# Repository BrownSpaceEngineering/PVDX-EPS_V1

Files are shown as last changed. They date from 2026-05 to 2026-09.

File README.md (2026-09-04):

# EPS_V1

Electrical Power System (EPS) for PVDX — battery charging, regulation, and power distribution.

## Status
- Design phase: layout
- Current rev: rev-1.3
- Contributors: Kelly Lin, Natalie Cavallo, Jayla Hsiung, Nick Cavallo, Emily Zhang, Dean Zweiman

## System overview

Four 2S battery packs (8x Tenergy 30005-0 18650 cells) feed a charge/regulation chain built entirely from dedicated power-management ICs, with no onboard MCU — charging, cell balancing, and telemetry are handled in hardware and reported to the compute board over I2C.

**Board sheets:**

- **Battery Pack 1–4**: one **MP2672AGD-0000-Z** charger per pack handles charging, discharging, and cell balancing without needing a microcontroller to manage the process. One **MAX17205** fuel gauge per pack reports state-of-charge and battery telemetry to the compute board over its own I2C pair (SDA/SCL), so each of the 4 packs has an independent data channel — a single fuel-gauge/charger failure doesn't take down monitoring for the other packs.
- **Charging Inputs**: the **MP28167GQ-Z** converts solar input down to a fixed 5V for charging. A **TPS2121RUXR** power mux sits between the solar and external-5V inputs and picks whichever is present, prioritizing external input — this is what lets the board charge normally on the bench (external 5V) without needing solar illumination, while still working correctly on orbit.
- **Converters**: three fixed-output regulators step the ~6–8.4V battery bus down to the rails other subsystems actually need: **TPS62133RGTR** (5V), **TPS62132RGTR** (3.3V), and **TPS61088RHLR** (12V boost, needed since 12V is above the battery bus voltage).
- **Connectors**: battery pack I/O, the RBF (remove-before-flight) pin, inhibit switches (mechanically disconnect batteries from load/ground when pressed — a safety requirement, not just a connector), and the ALRT signal and I2C breakout to the compute board.

### Repo layout

```
EPS_V1/
├── EPS_V1.kicad_pro / .kicad_sch / .kicad_pcb / .step
├── fp-lib-table, sym-lib-table
├── schematics/          # sub-sheets
├── libs/
│   ├── footprints.pretty/
│   ├── symbols/
│   └── 3dmodels/
├── spice/
│   ├── sims/
│   └── models/
├── tools/                # SPICE model translator script
└── manufacturing/
    └── rev-<N>_<date>/
        ├── gerbers/
        ├── bom/
        └── plots/
```

**Why 2S battery packs specifically:** 4x 2S (8 cells total) rather than one large pack — this is a mechanical/electrical packing choice under the ISS 80 Wh limit, and it gives pack-level redundancy (a single pack failure doesn't take down the whole EPS). It also matters electrically: a 2S pack has a ~6.0V floor, which the buck converters can cleanly step down to 5V and 3.3V — a single-cell pack's ~3.0V floor wouldn't support that.

## Key design notes

- **Charge voltage 4.2V, typical 3.6V, overdischarge floor raised from the cell's rated 2.75V to 3.0V** — added margin above the cell's absolute minimum.
- **MP2672A output current is being restricted below the MP28167GQ-Z's 3A capability** to stay under the board's actual current requirement (2.52A = 14/5×0.9). Open question below on whether that restriction should assume all 4 packs charging at once.
- **MAX17205's external-thermistor input is intentionally unused** — flight software reads temperature from the analog thermistor connection straight to the compute board instead, not through the fuel gauge.
- **TPS61088 (12V) key values:** 200kHz min switching frequency (840k resistor), 3A current limit (400k), PFM mode (MODE pin floating), R1 502k / R2 56k for 12V output, 2.2µH inductor per TI's recommended table.
- **Thermistor (NXFT15XV103FEAB025):** system draws 0.574mW through it against a 3mW rating — comfortable margin. Rated -40°C to 125°C.

## Simulations
- `spice/sims/` — EPS_U6, U2_EPS, U3_EPS, U6_EPS (regulator sims)
- `spice/models/` — TI PSpice models for TPS61088/TPS62132/TPS62133, both original and LTSpice-collapsed versions
- `tools/` — script + requirements to collapse TI's multi-line `.lib` continuation format into something LTSpice's autogenerator can parse

## Manufacturing history
| Rev | Date | Notes | Location |
|-----|---|---|---|
| 1.0 | 5/15/26 | First layout pass | `manufacturing/rev-1.0_2026-05-15/` |
| 1.2 | 8/7/26  | Prepared for schematic submittal | `manufacturing/rev-1.2_2026-08-07/` |
| 1.3 | 8/30/26  | Prepared for fabrication | `manufacturing/rev-1.3_2026-08-30/` |

## Open items / TBD
- S-band kill switch, FSW-configurable — not yet in design
- R_MID value for MP2672A — placeholder 0, needs datasheet-confirmed value (50Ω noted elsewhere from the fuel gauge datasheet — worth reconciling)
- Solar input voltage range (2.8–22V accepted) vs. actual solar board output — needs confirmation
- MP2672A max charge current restriction — should this account for a scenario where one pack is offline/broken?

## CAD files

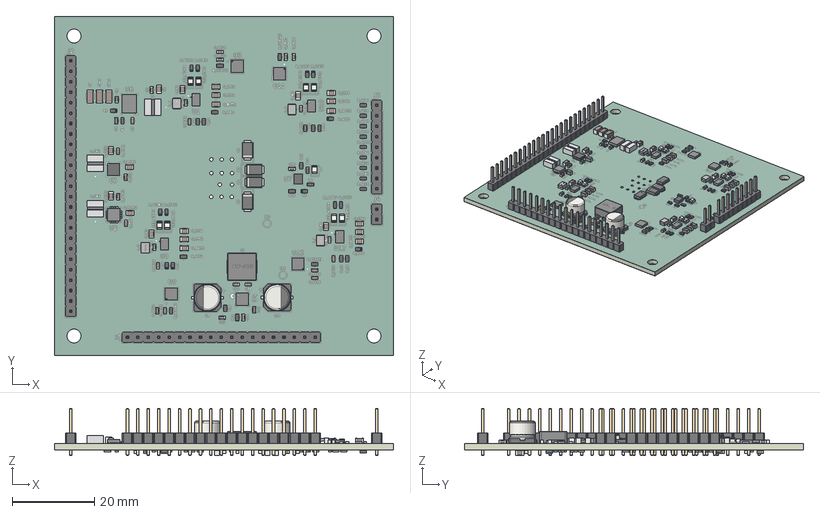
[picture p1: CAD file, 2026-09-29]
EPS_V1.step
82.5 x 82.5 x 11.5 mm
SON40P300X300X80-15N x 4
C_0805_2012Metric x 24
CP_Elec_6.3x5.4 x 2
R_0603_1608Metric x 68
C_0603_1608Metric x 38
MP2672A (QFN-18, 2x3) x 4
LED_0805_2012Metric x 9
D_SOD-128 x 4
BODY-QFN x 3
AMELA2012S-1R5MT x 4
IND_IFSC_1515AH_VIS x 3
MP28167GQ
PinHeader_1x25_P2.54mm_Vertical
MOLD
PinHeader_1x19_P2.54mm_Vertical
ASPI-7318-4R7M-T
C_1206_3216Metric x 3
PinHeader_1x09_P2.54mm_Vertical
PIN1-ID x 2
FRAME-RGT0016C
PinHeader_1x02_P2.54mm_Vertical
D_0603_1608Metric x 9
EPS_V1_silkscreen x 2
EPS_V1_soldermask x 2
EPS_V1_PCB

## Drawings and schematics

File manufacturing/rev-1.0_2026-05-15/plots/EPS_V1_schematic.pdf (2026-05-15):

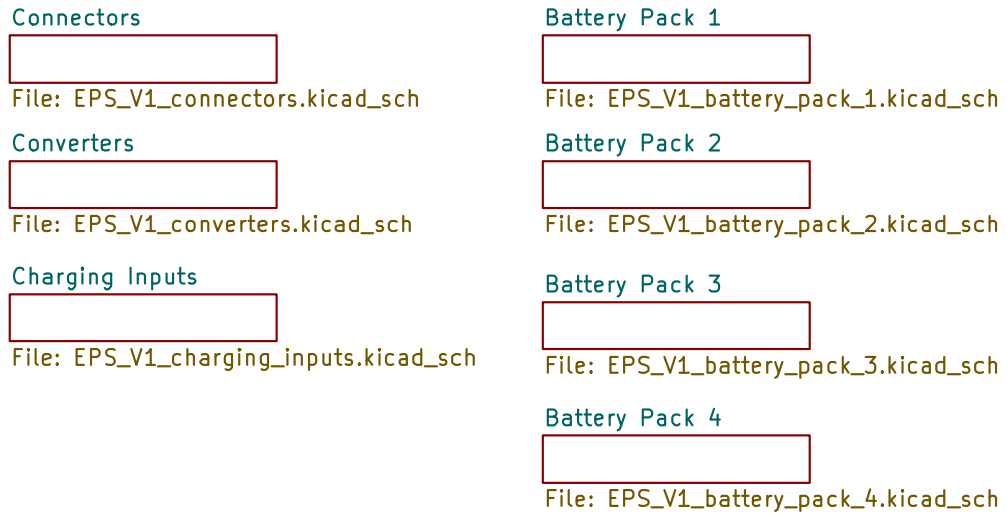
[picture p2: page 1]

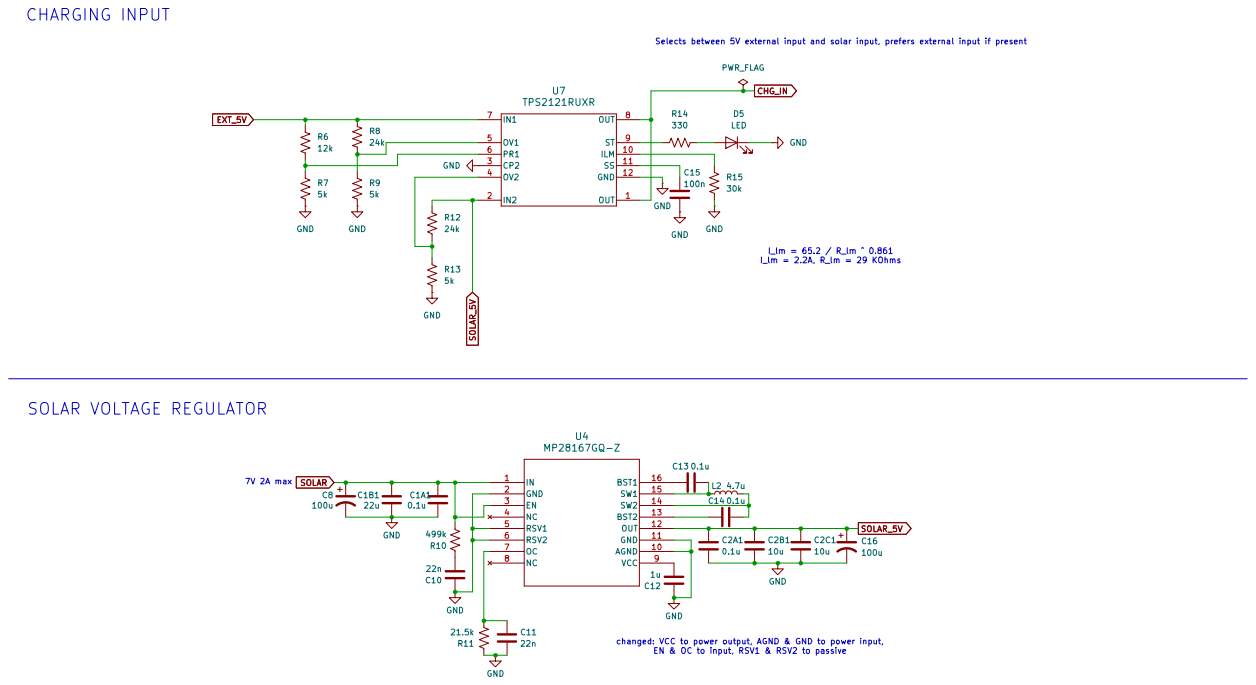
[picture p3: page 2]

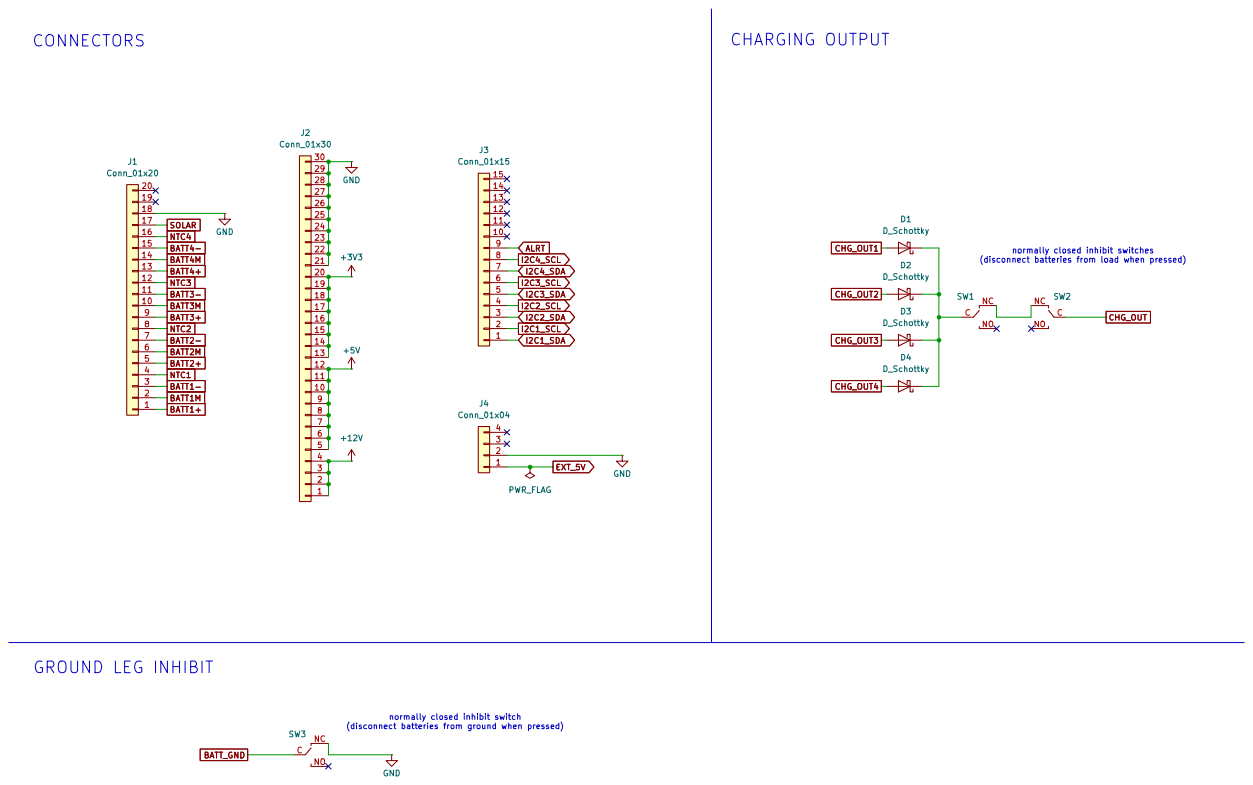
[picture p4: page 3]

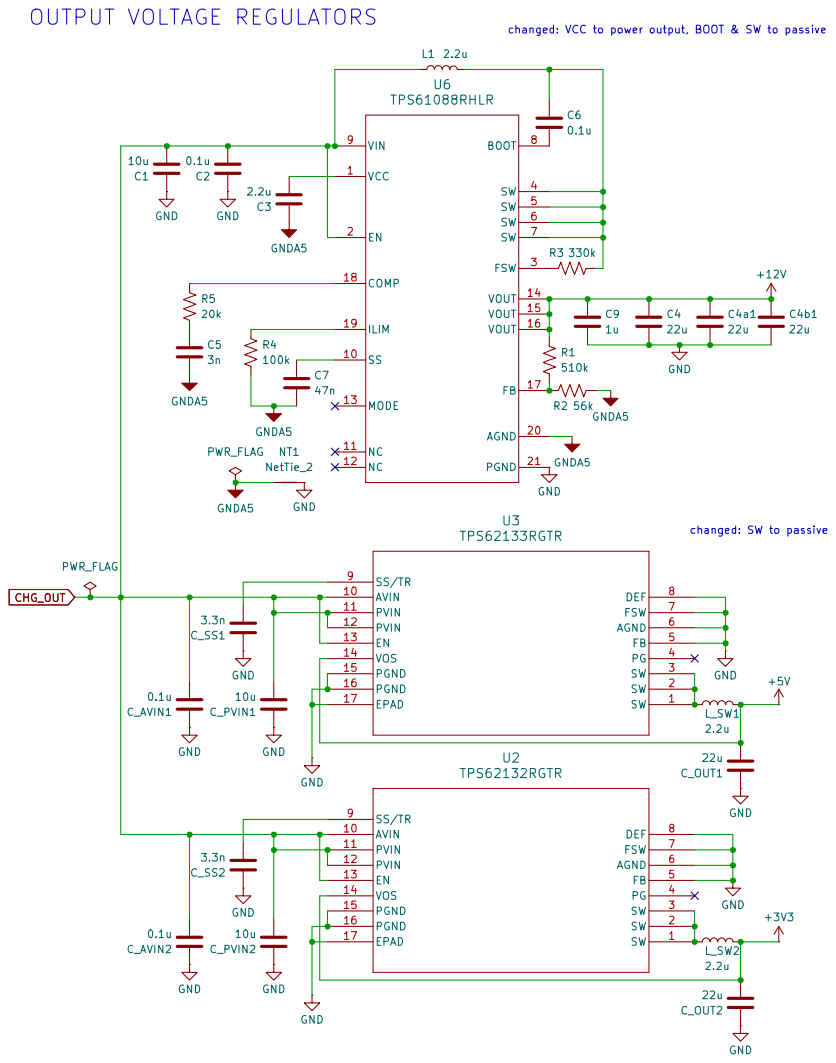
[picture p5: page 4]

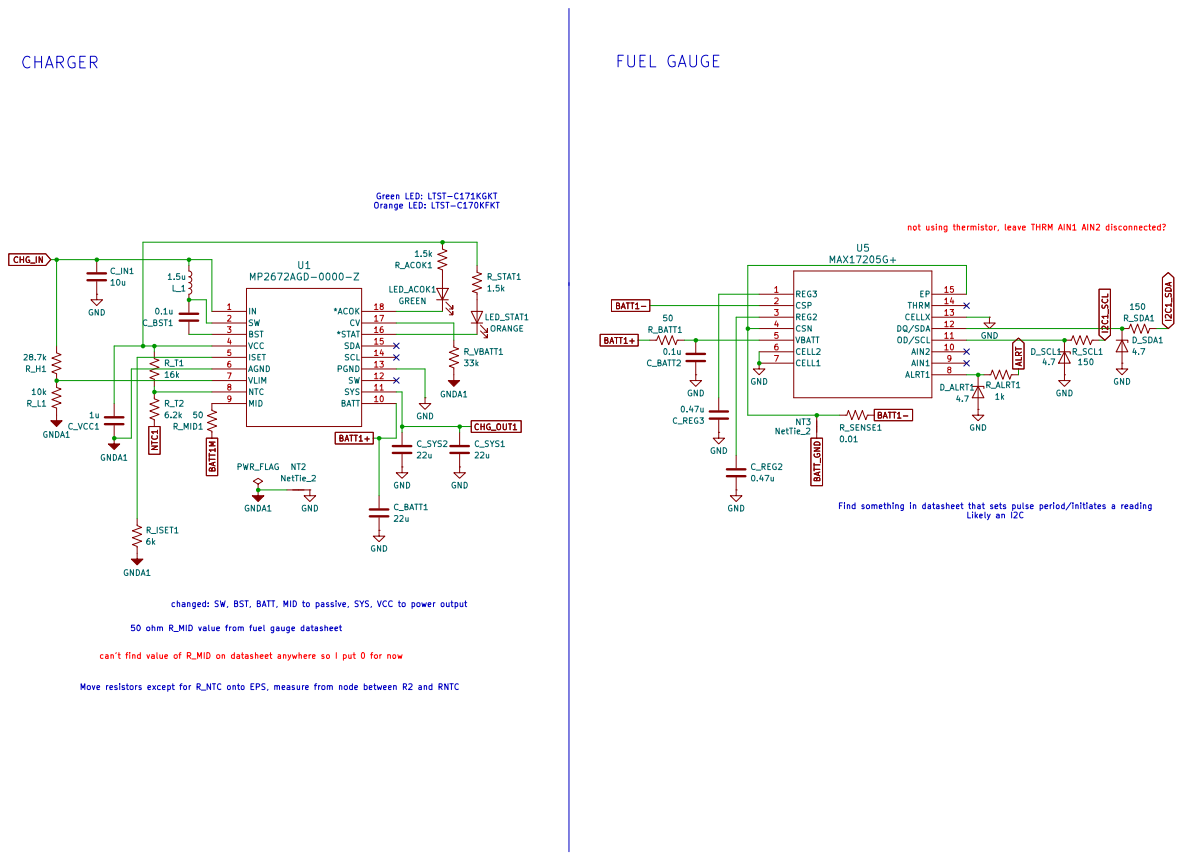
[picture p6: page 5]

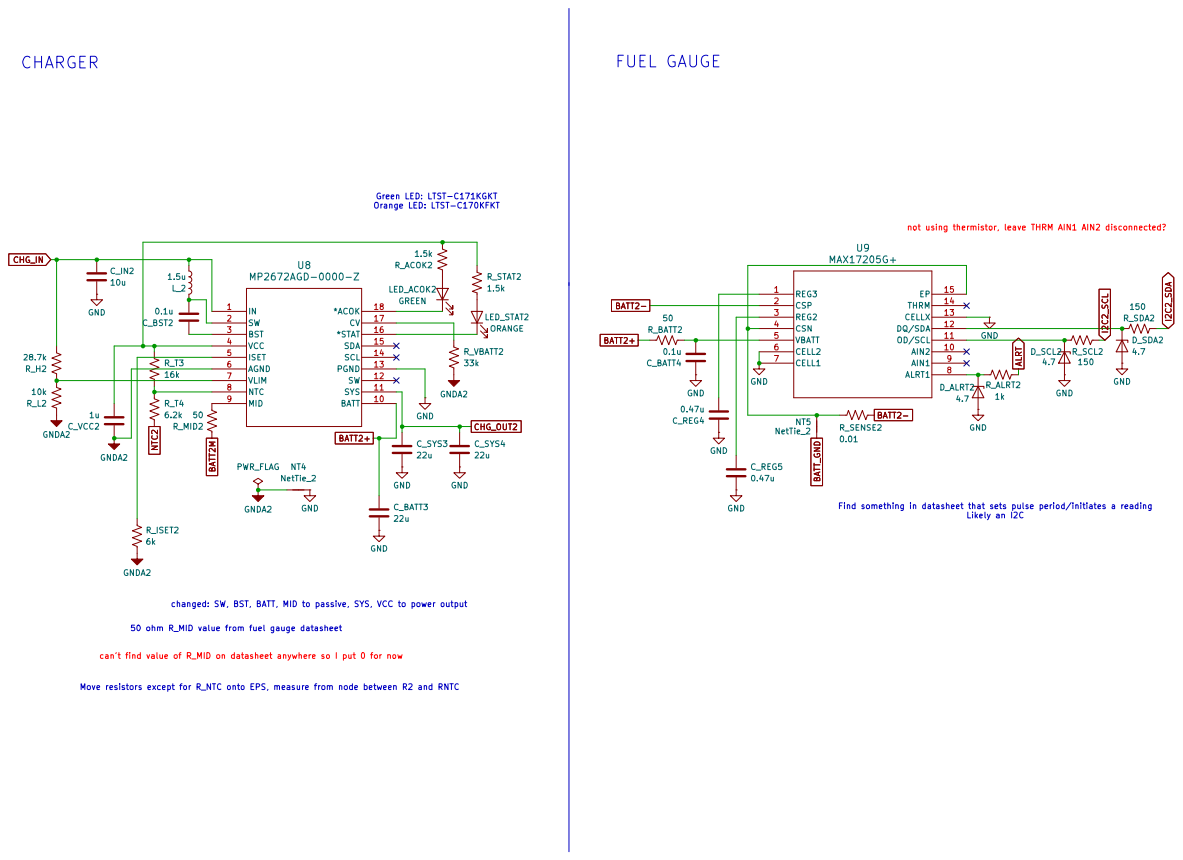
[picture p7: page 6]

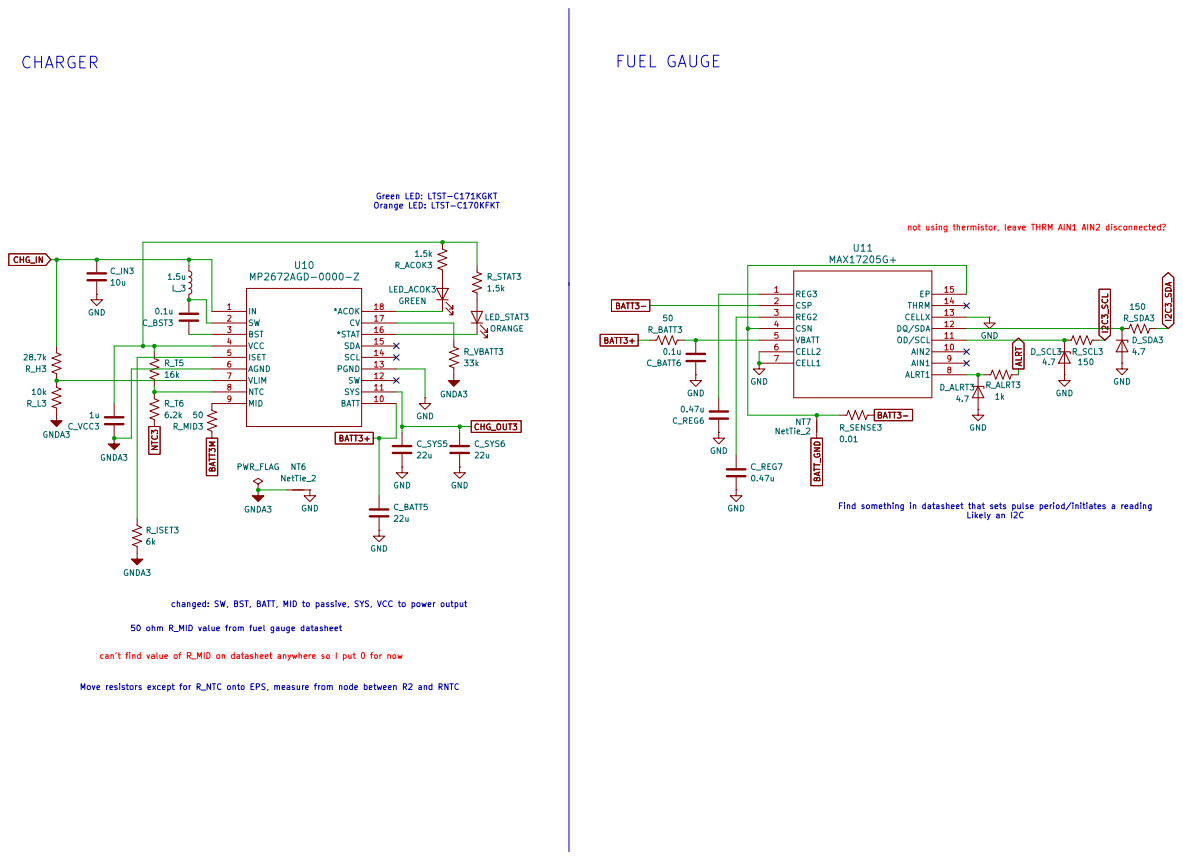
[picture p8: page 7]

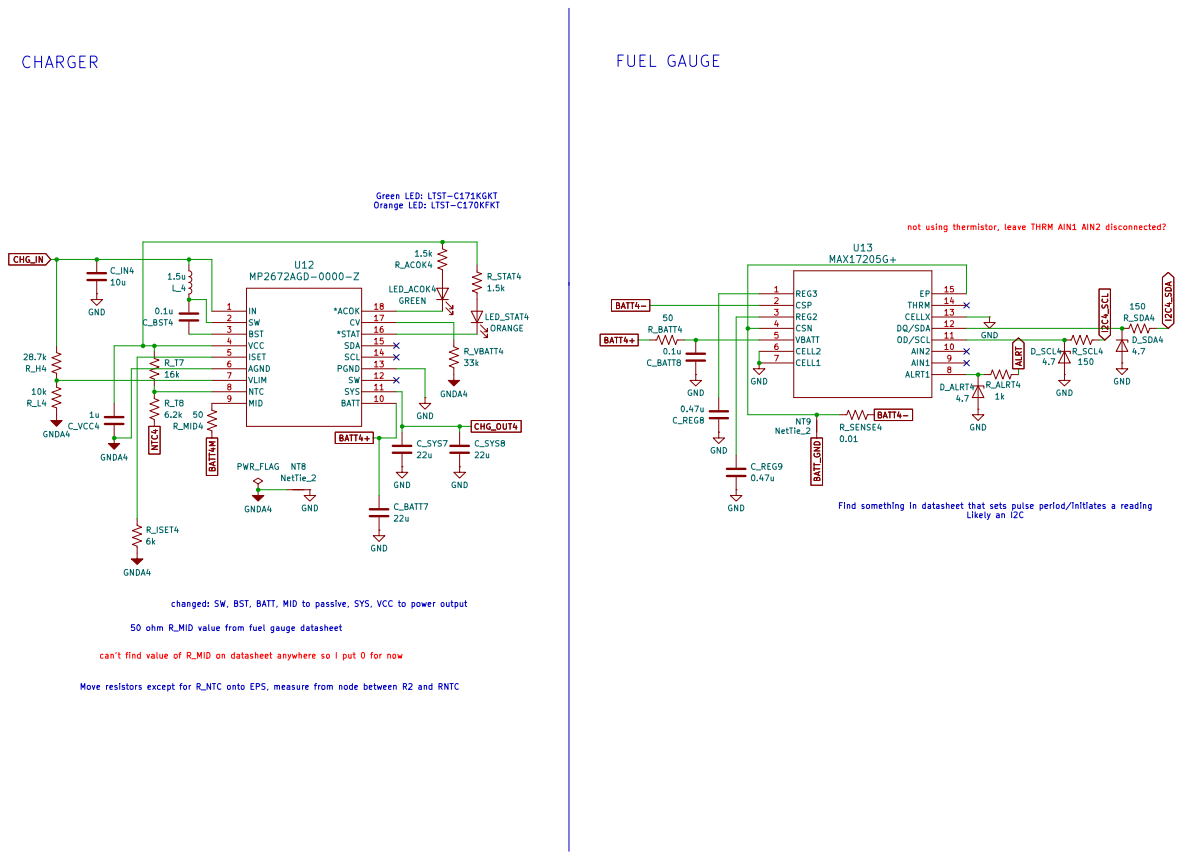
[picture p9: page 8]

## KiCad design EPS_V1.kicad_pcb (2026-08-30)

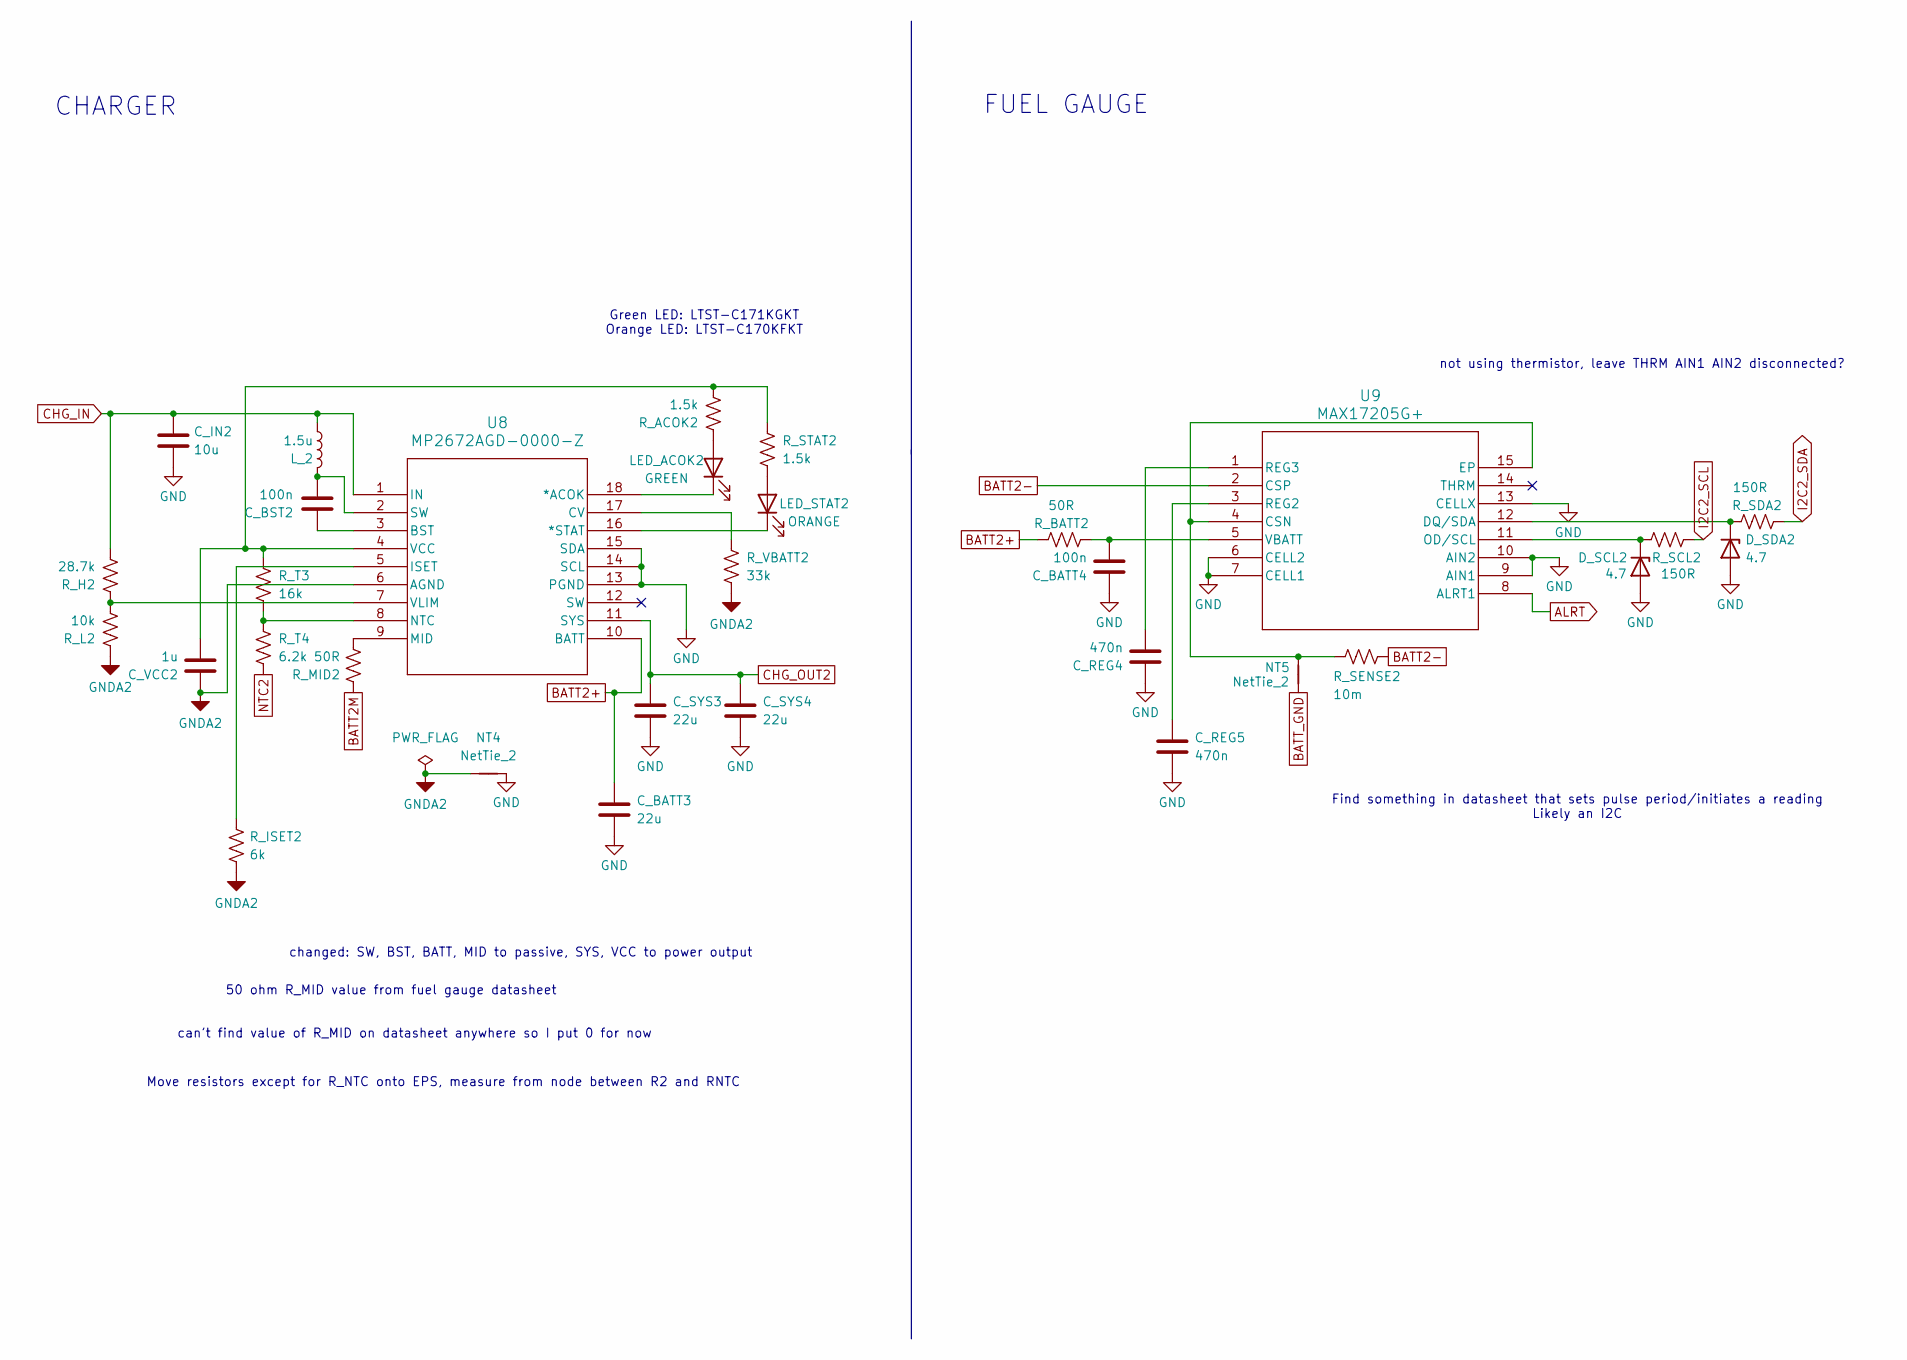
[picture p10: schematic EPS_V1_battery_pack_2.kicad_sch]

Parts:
C_BATT3: 22u; C_0805_2012Metric; Voltage Rating 25V
C_BATT4: 100n; C_0603_1608Metric; Voltage Rating 16V
C_BST2: 100n; C_0603_1608Metric; Voltage Rating 16V
C_IN2: 10u; C_0805_2012Metric; Voltage Rating 25V
C_REG4, C_REG5: 470n; C_0603_1608Metric; Voltage Rating 16V
C_SYS3, C_SYS4: 22u; C_0805_2012Metric; Voltage Rating 25V
C_VCC2: 1u; C_0603_1608Metric; Voltage Rating 16V
D_SCL2: 4.7; D_0603_1608Metric; MPN TVSL02V05C005 (check)
D_SDA2: 4.7; D_0603_1608Metric; MPN TVSL02V05C005 (check)
LED_ACOK2: GREEN; LED_0805_2012Metric; MPN LTST-C171KGKT
LED_STAT2: ORANGE; LED_0805_2012Metric; MPN LTST-C170KFKT
L_2: 1.5u; IND_AMELA2012S-1R5MT; MPN AMELA2012S-1R5MT
NT4, NT5: NetTie_2; NetTie-2_SMD_Pad0.5mm
R_ACOK2: 1.5k; R_0603_1608Metric
R_BATT2: 50R; R_0603_1608Metric
R_H2: 28.7k; R_0603_1608Metric
R_ISET2: 6k; R_0603_1608Metric
R_L2: 10k; R_0603_1608Metric
R_MID2: 50R; R_0603_1608Metric
R_SCL2: 150R; R_0603_1608Metric
R_SDA2: 150R; R_0603_1608Metric
R_SENSE2: 10m; R_0603_1608Metric
R_STAT2: 1.5k; R_0603_1608Metric
R_T3: 16k; R_0603_1608Metric
R_T4: 6.2k; R_0603_1608Metric
R_VBATT2: 33k; R_0603_1608Metric
U8: MP2672AGD-0000-Z; QFN-18_MP2672A_MNP
U9: MAX17205G+; 21-0137_T1433&plus_2C_MXM

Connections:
ALRT: U9.8 (ALRT1); also elsewhere on the board
BATT2+: C_BATT3.1, R_BATT2.1, U8.10 (BATT); also elsewhere on the board
BATT2-: R_SENSE2.1, U9.2 (CSP); also elsewhere on the board
BATT2M: R_MID2.1; also elsewhere on the board
BATT_GND: NT5.1; also elsewhere on the board
CHG_IN: C_IN2.1, L_2.1, R_H2.2, U8.1 (IN); also elsewhere on the board
CHG_OUT2: C_SYS3.1, C_SYS4.1, U8.11 (SYS); also elsewhere on the board
GND: C_BATT3.2, C_BATT4.1, C_IN2.2, C_REG4.1, C_REG5.2, C_SYS3.2, C_SYS4.2, D_SCL2.2 (A), D_SDA2.2 (A), NT4.2, U8.13 (PGND), U8.14 (SCL), U8.15 (SDA), U9.6 (CELL2), U9.7 (CELL1), U9.9 (AIN1), U9.10 (AIN2), U9.13 (CELLX); also elsewhere on the board
GNDA2: C_VCC2.1, NT4.1, R_ISET2.2, R_L2.1, R_VBATT2.2, U8.6 (AGND)
I2C2_SCL: R_SCL2.2; also elsewhere on the board
I2C2_SDA: R_SDA2.2; also elsewhere on the board
NTC2: R_T4.2; also elsewhere on the board
unnamed: C_BST2.2, L_2.2, U8.2 (SW)
unnamed: D_SCL2.1 (K), R_SCL2.1, U9.11 (OD/SCL)
unnamed: D_SDA2.1 (K), R_SDA2.1, U9.12 (DQ/SDA)
unnamed: LED_ACOK2.2 (A), R_ACOK2.1
unnamed: LED_ACOK2.1 (K), U8.18 (*ACOK)
unnamed: LED_STAT2.2 (A), R_STAT2.2
unnamed: LED_STAT2.1 (K), U8.16 (*STAT)
unnamed: C_BST2.1, U8.3 (BST)
unnamed: R_VBATT2.1, U8.17 (CV)
unnamed: R_ISET2.1, U8.5 (ISET)
unnamed: R_MID2.2, U8.9 (MID)
unnamed: R_T3.2, R_T4.1, U8.8 (NTC)
unnamed: C_VCC2.2, R_ACOK2.2, R_STAT2.1, R_T3.1, U8.4 (VCC)
unnamed: R_H2.1, R_L2.2, U8.7 (VLIM)
unnamed: NT5.2, R_SENSE2.2, U9.4 (CSN), U9.15 (EP)
unnamed: C_REG5.1, U9.3 (REG2)
unnamed: C_REG4.2, U9.1 (REG3)
unnamed: C_BATT4.2, R_BATT2.2, U9.5 (VBATT)

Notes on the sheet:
Find something in datasheet that sets pulse period/initiates a reading Likely an I2C
CHARGER
Move resistors except for R_NTC onto EPS, measure from node between R2 and RNTC
50 ohm R_MID value from fuel gauge datasheet
FUEL GAUGE
not using thermistor, leave THRM AIN1 AIN2 disconnected?
can't find value of R_MID on datasheet anywhere so I put 0 for now
Green LED: LTST-C171KGKT Orange LED: LTST-C170KFKT
changed: SW, BST, BATT, MID to passive, SYS, VCC to power output

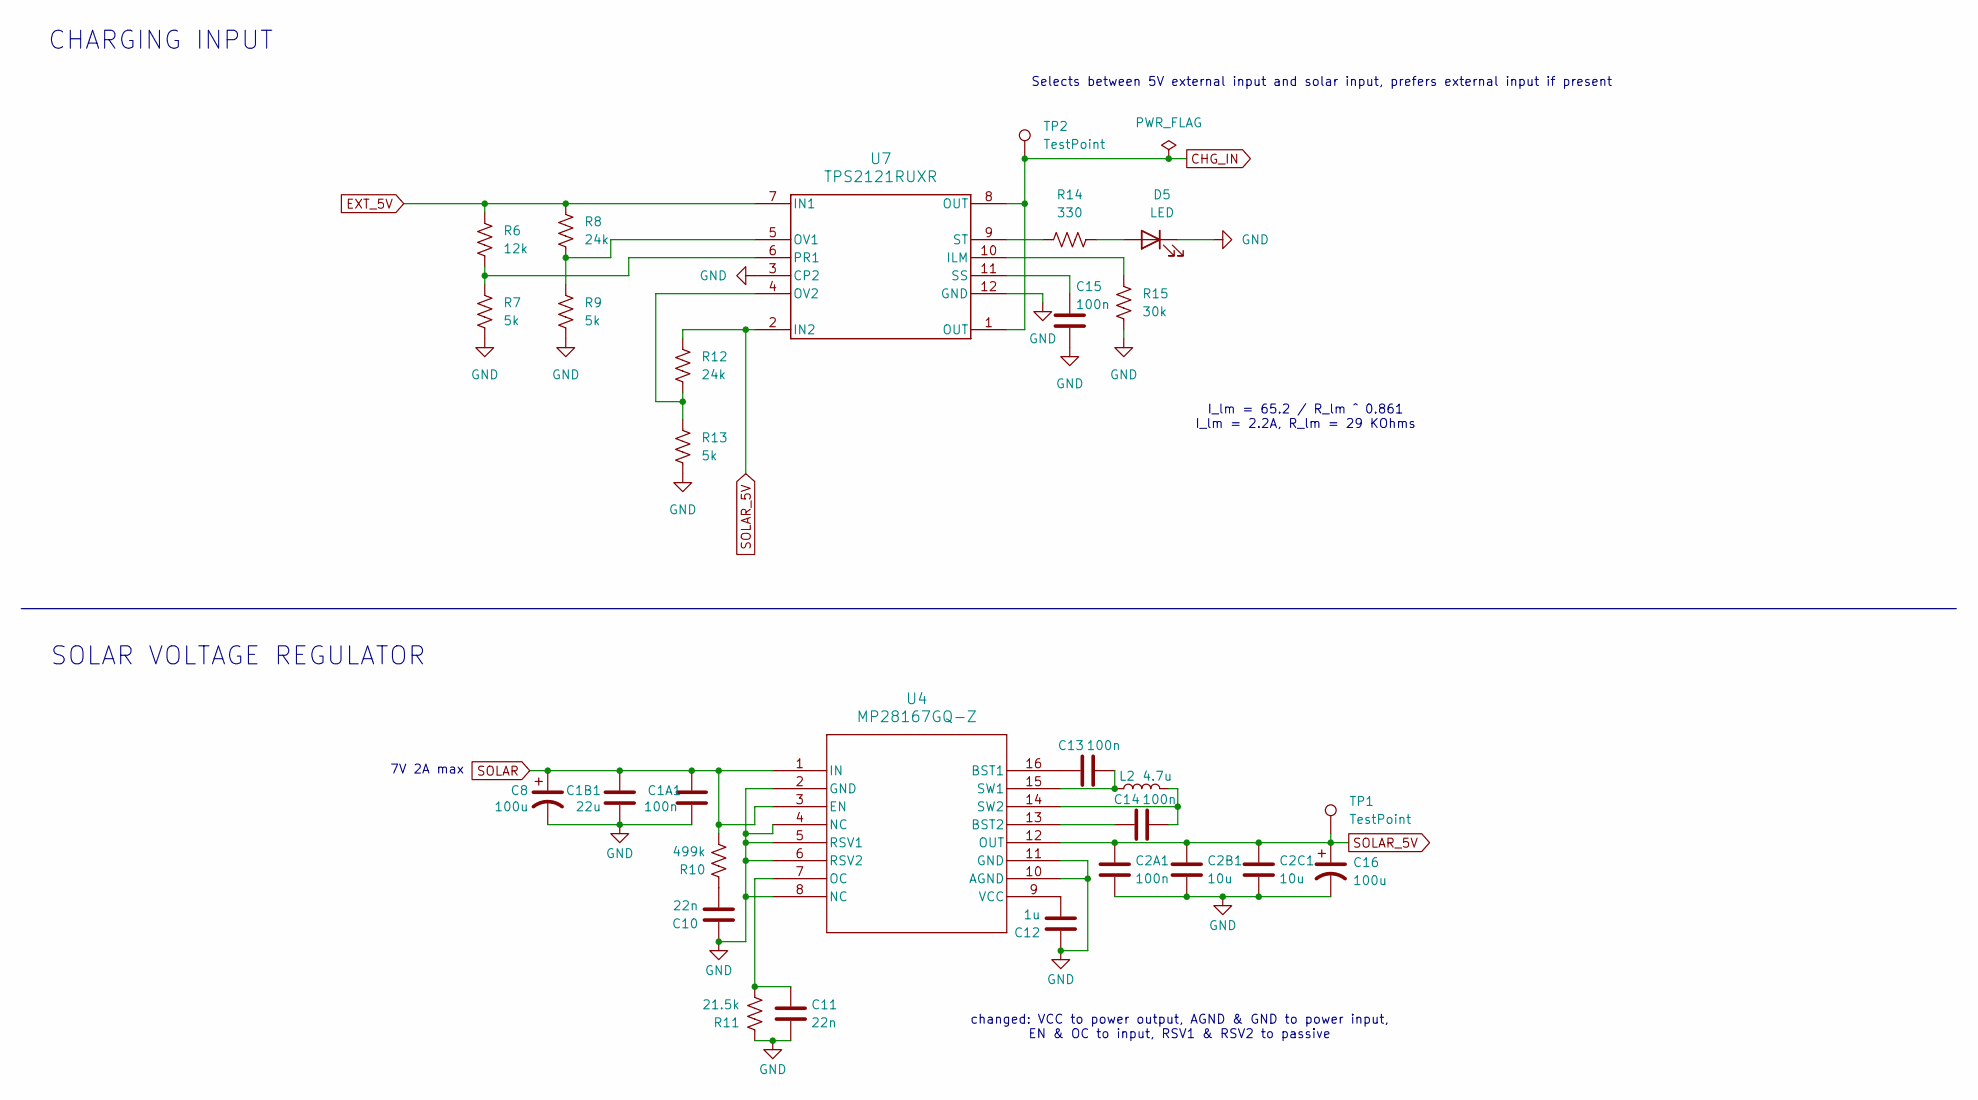
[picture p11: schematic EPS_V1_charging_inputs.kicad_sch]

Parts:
C1A1, C2A1: 100n; C_0603_1608Metric; Voltage Rating 16V
C1B1: 22u; C_0805_2012Metric; Voltage Rating 25V
C2B1, C2C1: 10u; C_0805_2012Metric; Voltage Rating 16V
C8, C16: 100u; CP_Elec_6.3x5.4; Voltage Rating 16V
C10, C11: 22n; C_0603_1608Metric; Voltage Rating 10V
C12: 1u; C_0603_1608Metric; Voltage Rating 16V
C13, C14: 100n; C_0603_1608Metric; Voltage Rating 10V
C15: 100n; C_0603_1608Metric
D5: LED; LED_0805_2012Metric
L2: 4.7u; IND_ASPI-7318-4R7M-T; MPN ASPI-7318-4R7M-T
R6: 12k; R_0603_1608Metric
R7, R9, R13: 5k; R_0603_1608Metric
R8, R12: 24k; R_0603_1608Metric
R10: 499k; R_0603_1608Metric
R11: 21.5k; R_0603_1608Metric
R14: 330; R_0603_1608Metric
R15: 30k; R_0603_1608Metric
TP1, TP2: TestPoint; TestPoint_Pad_D1.5mm
U4: MP28167GQ-Z; QFN-16_MP28167GQ_MNP
U7: TPS2121RUXR; RUX0012A

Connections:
CHG_IN: TP2.1 (1_1), U7.1 (OUT), U7.8 (OUT); also elsewhere on the board
EXT_5V: R6.2, R8.2, U7.7 (IN1); also elsewhere on the board
GND: C1A1.2, C1B1.1, C2A1.2, C2B1.2, C2C1.2, C8.2, C10.1, C11.2, C12.1, C15.2, C16.2, D5.1 (K), R7.1, R9.1, R11.1, R13.1, R15.1, U4.2 (GND), U4.4 (NC), U4.5 (RSV1), U4.6 (RSV2), U4.8 (NC), U4.10 (AGND), U4.11 (GND), U7.3 (CP2), U7.12 (GND); also elsewhere on the board
unnamed: C10.2, R10.1
unnamed: D5.2 (A), R14.1
unnamed: C13.1, U4.16 (BST1)
unnamed: C14.1, U4.13 (BST2)
unnamed: C11.1, R11.2, U4.7 (OC)
unnamed: C13.2, L2.1, U4.15 (SW1)
unnamed: C14.2, L2.2, U4.14 (SW2)
unnamed: C12.2, U4.9 (VCC)
unnamed: R15.2, U7.10 (ILM)
unnamed: R8.1, R9.2, U7.5 (OV1)
unnamed: R12.1, R13.2, U7.4 (OV2)
unnamed: R6.1, R7.2, U7.6 (PR1)
unnamed: C15.1, U7.11 (SS)
unnamed: R14.2, U7.9 (ST)
SOLAR: C1A1.1, C1B1.2, C8.1, R10.2, U4.1 (IN), U4.3 (EN); also elsewhere on the board
SOLAR_5V: C2A1.1, C2B1.1, C2C1.1, C16.1, R12.2, TP1.1 (1_1), U4.12 (OUT), U7.2 (IN2)

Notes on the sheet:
7V 2A max
changed: VCC to power output, AGND & GND to power input, EN & OC to input, RSV1 & RSV2 to passive
Selects between 5V external input and solar input, prefers external input if present
CHARGING INPUT
SOLAR VOLTAGE REGULATOR
I_lm = 65.2 / R_lm ^ 0.861 I_lm = 2.2A, R_lm = 29 KOhms

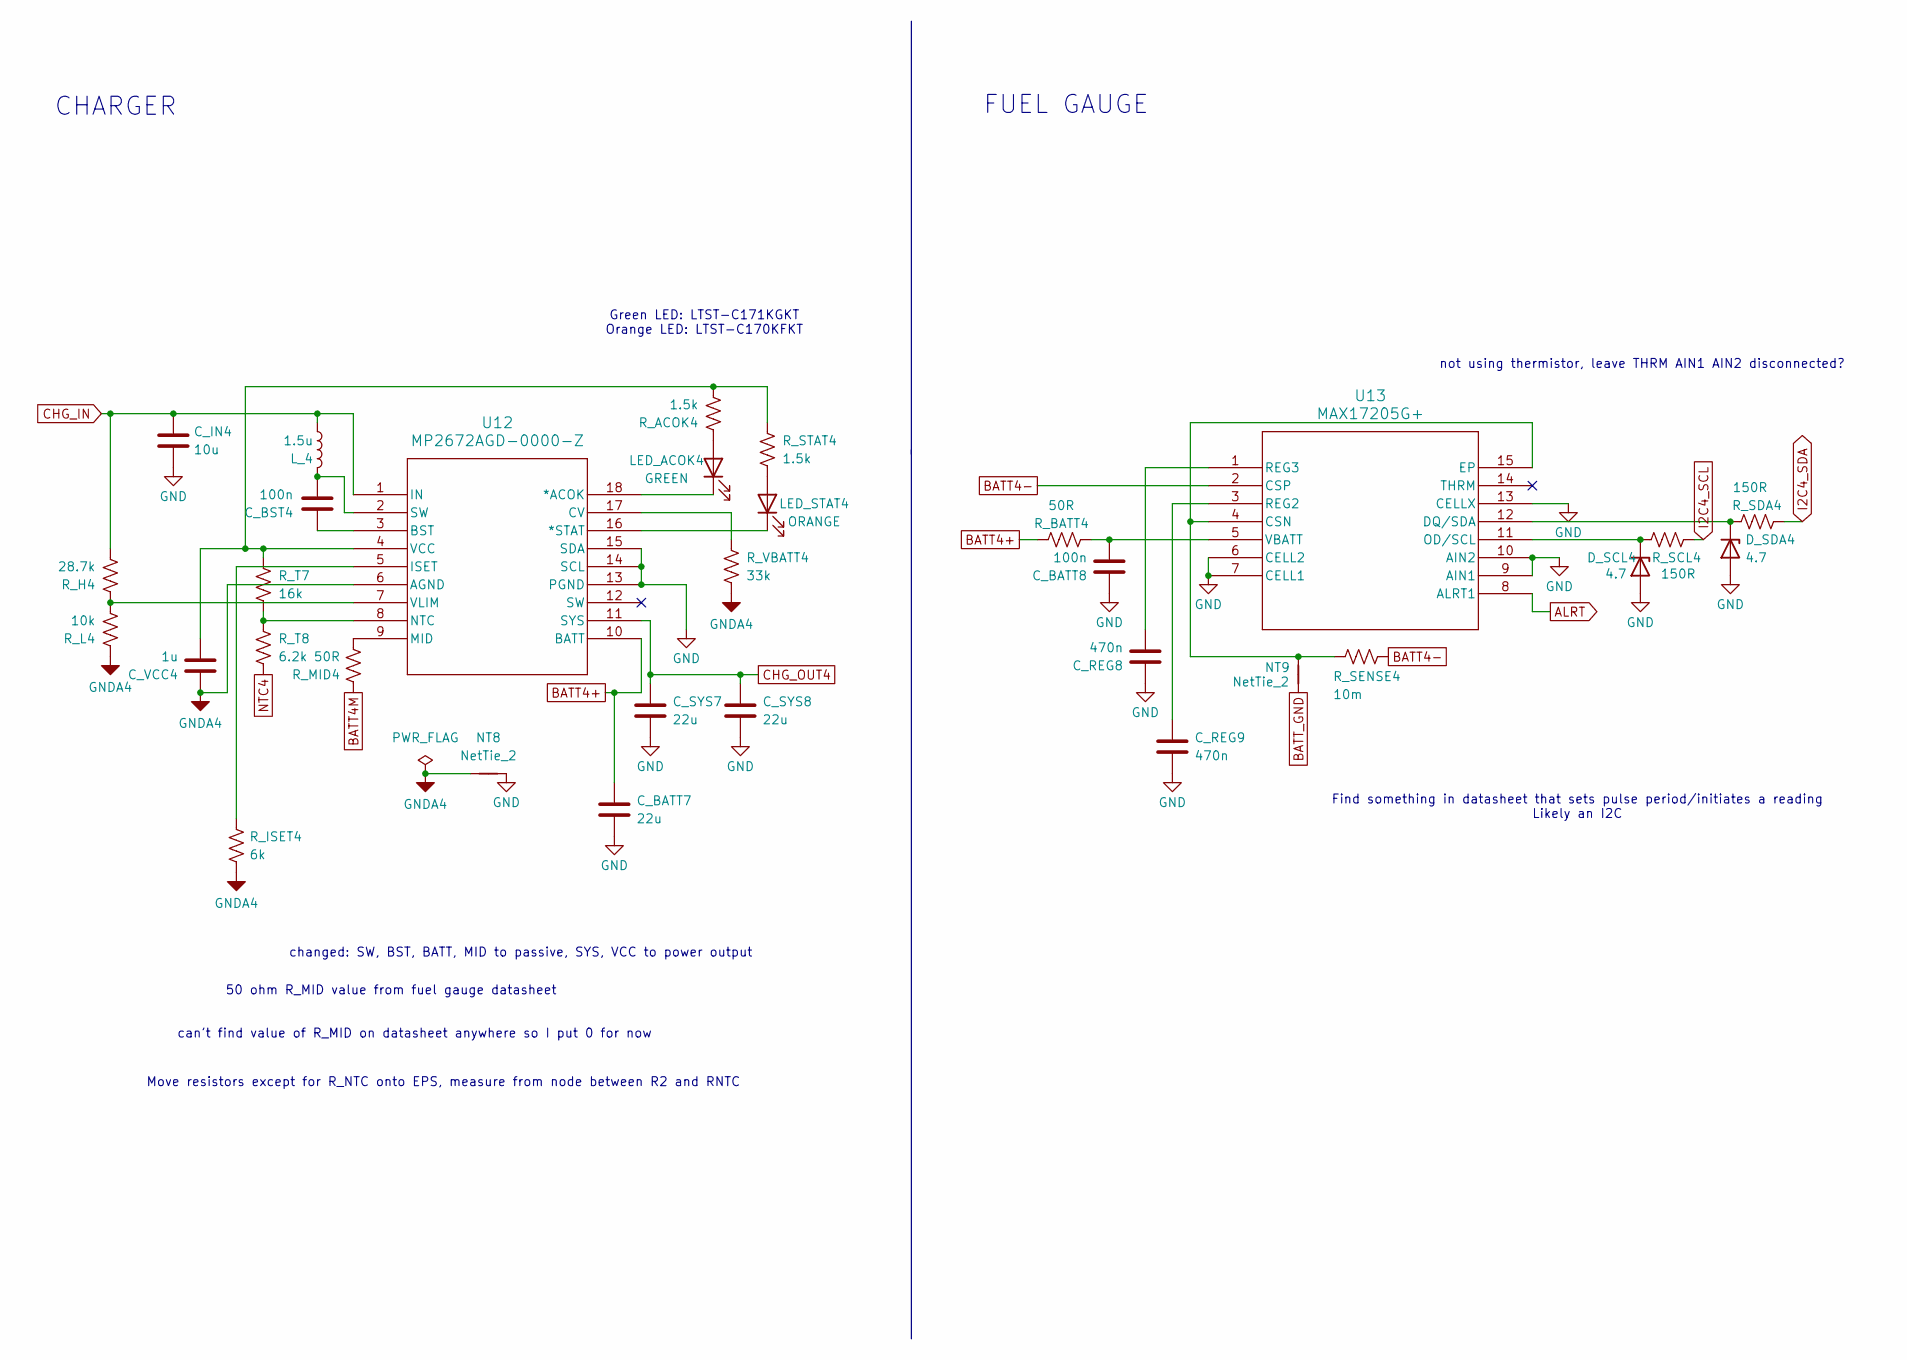
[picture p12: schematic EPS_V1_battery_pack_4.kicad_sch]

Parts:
C_BATT7: 22u; C_0805_2012Metric; Voltage Rating 25V
C_BATT8: 100n; C_0603_1608Metric; Voltage Rating 16V
C_BST4: 100n; C_0603_1608Metric; Voltage Rating 16V
C_IN4: 10u; C_0805_2012Metric; Voltage Rating 25V
C_REG8, C_REG9: 470n; C_0603_1608Metric; Voltage Rating 16V
C_SYS7, C_SYS8: 22u; C_0805_2012Metric; Voltage Rating 25V
C_VCC4: 1u; C_0603_1608Metric; Voltage Rating 16V
D_SCL4: 4.7; D_0603_1608Metric; MPN TVSL02V05C005 (check)
D_SDA4: 4.7; D_0603_1608Metric; MPN TVSL02V05C005 (check)
LED_ACOK4: GREEN; LED_0805_2012Metric; MPN LTST-C171KGKT
LED_STAT4: ORANGE; LED_0805_2012Metric; MPN LTST-C170KFKT
L_4: 1.5u; IND_AMELA2012S-1R5MT; MPN AMELA2012S-1R5MT
NT8, NT9: NetTie_2; NetTie-2_SMD_Pad0.5mm
R_ACOK4: 1.5k; R_0603_1608Metric
R_BATT4: 50R; R_0603_1608Metric
R_H4: 28.7k; R_0603_1608Metric
R_ISET4: 6k; R_0603_1608Metric
R_L4: 10k; R_0603_1608Metric
R_MID4: 50R; R_0603_1608Metric
R_SCL4: 150R; R_0603_1608Metric
R_SDA4: 150R; R_0603_1608Metric
R_SENSE4: 10m; R_0603_1608Metric
R_STAT4: 1.5k; R_0603_1608Metric
R_T7: 16k; R_0603_1608Metric
R_T8: 6.2k; R_0603_1608Metric
R_VBATT4: 33k; R_0603_1608Metric
U12: MP2672AGD-0000-Z; QFN-18_MP2672A_MNP
U13: MAX17205G+; 21-0137_T1433&plus_2C_MXM

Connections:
ALRT: U13.8 (ALRT1); also elsewhere on the board
BATT4+: C_BATT7.1, R_BATT4.1, U12.10 (BATT); also elsewhere on the board
BATT4-: R_SENSE4.1, U13.2 (CSP); also elsewhere on the board
BATT4M: R_MID4.1; also elsewhere on the board
BATT_GND: NT9.1; also elsewhere on the board
CHG_IN: C_IN4.1, L_4.1, R_H4.2, U12.1 (IN); also elsewhere on the board
CHG_OUT4: C_SYS7.1, C_SYS8.1, U12.11 (SYS); also elsewhere on the board
GND: C_BATT7.2, C_BATT8.1, C_IN4.2, C_REG8.1, C_REG9.2, C_SYS7.2, C_SYS8.2, D_SCL4.2 (A), D_SDA4.2 (A), NT8.2, U12.13 (PGND), U12.14 (SCL), U12.15 (SDA), U13.6 (CELL2), U13.7 (CELL1), U13.9 (AIN1), U13.10 (AIN2), U13.13 (CELLX); also elsewhere on the board
GNDA4: C_VCC4.1, NT8.1, R_ISET4.2, R_L4.1, R_VBATT4.2, U12.6 (AGND)
I2C4_SCL: R_SCL4.2; also elsewhere on the board
I2C4_SDA: R_SDA4.2; also elsewhere on the board
NTC4: R_T8.2; also elsewhere on the board
unnamed: C_BST4.2, L_4.2, U12.2 (SW)
unnamed: D_SCL4.1 (K), R_SCL4.1, U13.11 (OD/SCL)
unnamed: D_SDA4.1 (K), R_SDA4.1, U13.12 (DQ/SDA)
unnamed: LED_ACOK4.2 (A), R_ACOK4.1
unnamed: LED_ACOK4.1 (K), U12.18 (*ACOK)
unnamed: LED_STAT4.2 (A), R_STAT4.2
unnamed: LED_STAT4.1 (K), U12.16 (*STAT)
unnamed: C_BST4.1, U12.3 (BST)
unnamed: R_VBATT4.1, U12.17 (CV)
unnamed: R_ISET4.1, U12.5 (ISET)
unnamed: R_MID4.2, U12.9 (MID)
unnamed: R_T7.2, R_T8.1, U12.8 (NTC)
unnamed: C_VCC4.2, R_ACOK4.2, R_STAT4.1, R_T7.1, U12.4 (VCC)
unnamed: R_H4.1, R_L4.2, U12.7 (VLIM)
unnamed: NT9.2, R_SENSE4.2, U13.4 (CSN), U13.15 (EP)
unnamed: C_REG9.1, U13.3 (REG2)
unnamed: C_REG8.2, U13.1 (REG3)
unnamed: C_BATT8.2, R_BATT4.2, U13.5 (VBATT)

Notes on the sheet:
CHARGER
50 ohm R_MID value from fuel gauge datasheet
Green LED: LTST-C171KGKT Orange LED: LTST-C170KFKT
Move resistors except for R_NTC onto EPS, measure from node between R2 and RNTC
FUEL GAUGE
Find something in datasheet that sets pulse period/initiates a reading Likely an I2C
not using thermistor, leave THRM AIN1 AIN2 disconnected?
can't find value of R_MID on datasheet anywhere so I put 0 for now
changed: SW, BST, BATT, MID to passive, SYS, VCC to power output

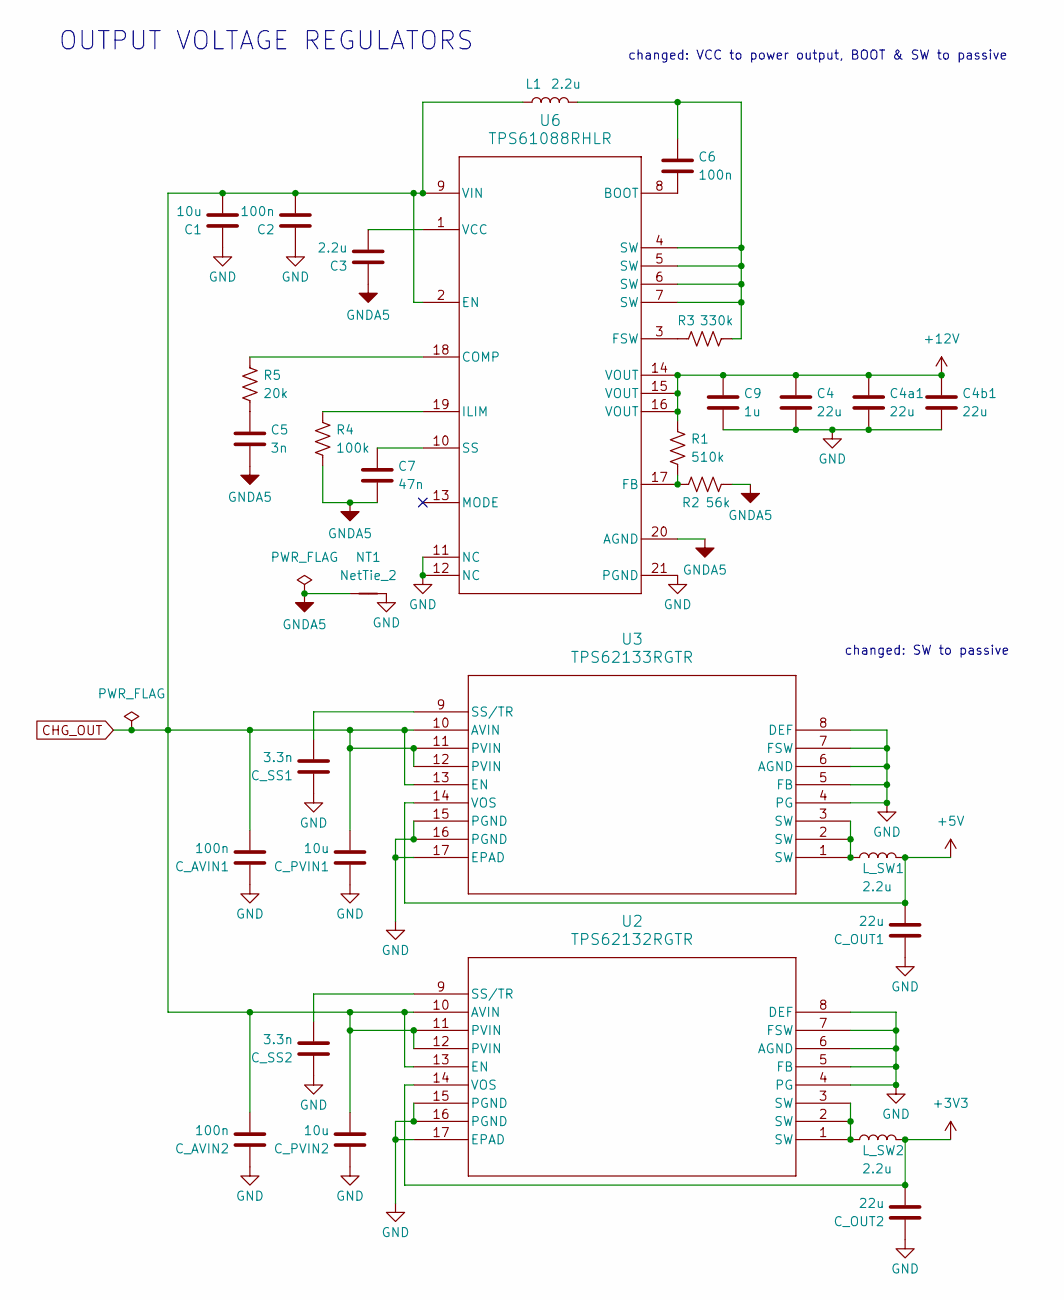
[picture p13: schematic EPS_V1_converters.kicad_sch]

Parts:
C1: 10u; C_0805_2012Metric; Voltage Rating 25V
C2, C6: 100n; C_0603_1608Metric; Voltage Rating 16V
C3: 2.2u; C_0603_1608Metric; Voltage Rating 16V
C4, C4a1, C4b1: 22u; C_1206_3216Metric; Voltage Rating 35V
C5: 3n; C_0603_1608Metric; Voltage Rating 10V
C7: 47n; C_0603_1608Metric; Voltage Rating 10V
C9: 1u; C_0603_1608Metric; Voltage Rating 25V
C_AVIN1, C_AVIN2: 100n; C_0603_1608Metric; Voltage Rating 16V
C_OUT1: 22u; C_0805_2012Metric; Voltage Rating 25V
C_OUT2: 22u; C_0805_2012Metric; Voltage Rating 16V
C_PVIN1, C_PVIN2: 10u; C_0805_2012Metric; Voltage Rating 25V
C_SS1, C_SS2: 3.3n; C_0603_1608Metric; Voltage Rating 16V
L1: 2.2u; IND_IFSC_1515AH_VIS; MPN IFSC1515AHER2R2M01
L_SW1, L_SW2: 2.2u; IND_IFSC_1515AH_VIS; MPN IFSC1515AHER2R2M01
NT1: NetTie_2; NetTie-2_SMD_Pad0.5mm
R1: 510k; R_0603_1608Metric
R2: 56k; R_0603_1608Metric
R3: 330k; R_0603_1608Metric
R4: 100k; R_0603_1608Metric
R5: 20k; R_0603_1608Metric
U2: TPS62132RGTR; RGT16_1P7X1P7
U3: TPS62133RGTR; RGT0016C
U6: TPS61088RHLR; RHL0020A

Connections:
+3V3: C_OUT2.2, L_SW2.2, U2.14 (VOS); also elsewhere on the board
+5V: C_OUT1.2, L_SW1.2, U3.14 (VOS); also elsewhere on the board
+12V: C4.1, C4a1.1, C4b1.1, C9.1, R1.1, U6.14 (VOUT), U6.15 (VOUT), U6.16 (VOUT); also elsewhere on the board
CHG_OUT: C1.2, C2.2, C_AVIN1.2, C_AVIN2.2, C_PVIN1.2, C_PVIN2.2, L1.1, U2.10 (AVIN), U2.11 (PVIN), U2.12 (PVIN), U2.13 (EN), U3.10 (AVIN), U3.11 (PVIN), U3.12 (PVIN), U3.13 (EN), U6.2 (EN), U6.9 (VIN); also elsewhere on the board
GND: C1.1, C2.1, C4.2, C4a1.2, C4b1.2, C9.2, C_AVIN1.1, C_AVIN2.1, C_OUT1.1, C_OUT2.1, C_PVIN1.1, C_PVIN2.1, C_SS1.1, C_SS2.1, NT1.2, U2.4 (PG), U2.5 (FB), U2.6 (AGND), U2.7 (FSW), U2.8 (DEF), U2.15 (PGND), U2.16 (PGND), U2.17 (EPAD), U3.4 (PG), U3.5 (FB), U3.6 (AGND), U3.7 (FSW), U3.8 (DEF), U3.15 (PGND), U3.16 (PGND), U3.17 (EPAD), U6.11 (NC), U6.12 (NC), U6.21 (PGND); also elsewhere on the board
GNDA5: C3.1, C5.2, C7.2, NT1.1, R2.1, R4.2, U6.20 (AGND)
unnamed: C5.1, R5.2
unnamed: C6.1, L1.2, R3.2, U6.4 (SW), U6.5 (SW), U6.6 (SW), U6.7 (SW)
unnamed: L_SW1.1, U3.1 (SW), U3.2 (SW), U3.3 (SW)
unnamed: L_SW2.1, U2.1 (SW), U2.2 (SW), U2.3 (SW)
unnamed: C_SS2.2, U2.9 (SS/TR)
unnamed: C_SS1.2, U3.9 (SS/TR)
unnamed: C6.2, U6.8 (BOOT)
unnamed: R5.1, U6.18 (COMP)
unnamed: R1.2, R2.2, U6.17 (FB)
unnamed: R3.1, U6.3 (FSW)
unnamed: R4.1, U6.19 (ILIM)
unnamed: C7.1, U6.10 (SS)
unnamed: C3.2, U6.1 (VCC)

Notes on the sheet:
OUTPUT VOLTAGE REGULATORS
changed: VCC to power output, BOOT & SW to passive
changed: SW to passive

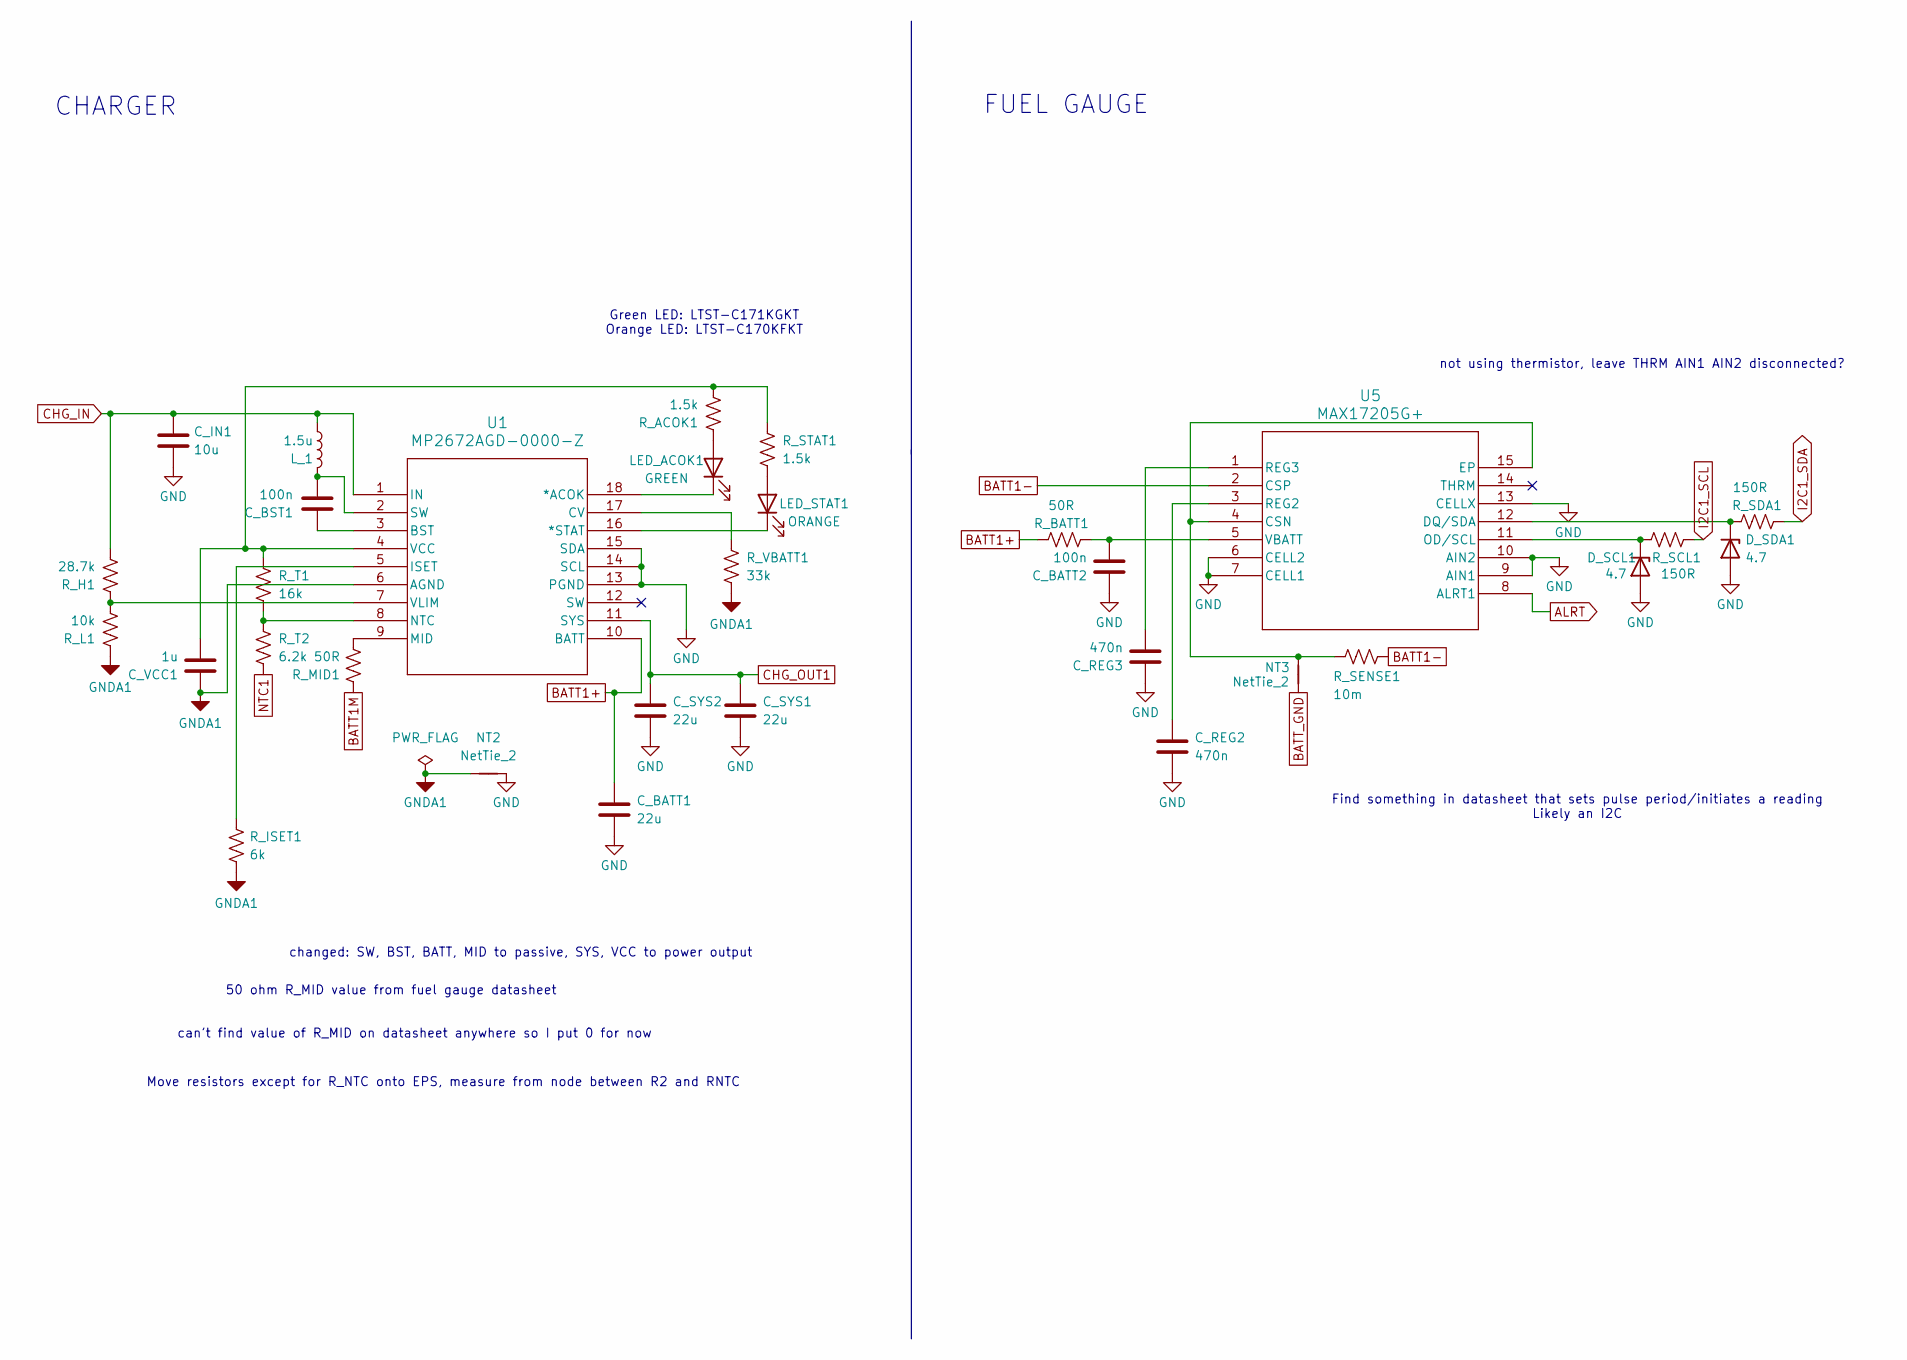
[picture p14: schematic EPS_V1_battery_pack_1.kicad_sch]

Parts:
C_BATT1: 22u; C_0805_2012Metric; Voltage Rating 25V
C_BATT2: 100n; C_0603_1608Metric; Voltage Rating 16V
C_BST1: 100n; C_0603_1608Metric; Voltage Rating 16V
C_IN1: 10u; C_0805_2012Metric; Voltage Rating 25V
C_REG2, C_REG3: 470n; C_0603_1608Metric; Voltage Rating 16V
C_SYS1, C_SYS2: 22u; C_0805_2012Metric; Voltage Rating 25V
C_VCC1: 1u; C_0603_1608Metric; Voltage Rating 16V
D_SCL1: 4.7; D_0603_1608Metric; MPN TVSL02V05C005 (check)
D_SDA1: 4.7; D_0603_1608Metric; MPN TVSL02V05C005 (check)
LED_ACOK1: GREEN; LED_0805_2012Metric; MPN LTST-C171KGKT
LED_STAT1: ORANGE; LED_0805_2012Metric; MPN LTST-C170KFKT
L_1: 1.5u; IND_AMELA2012S-1R5MT; MPN AMELA2012S-1R5MT
NT2, NT3: NetTie_2; NetTie-2_SMD_Pad0.5mm
R_ACOK1: 1.5k; R_0603_1608Metric
R_BATT1: 50R; R_0603_1608Metric
R_H1: 28.7k; R_0603_1608Metric
R_ISET1: 6k; R_0603_1608Metric
R_L1: 10k; R_0603_1608Metric
R_MID1: 50R; R_0603_1608Metric
R_SCL1: 150R; R_0603_1608Metric
R_SDA1: 150R; R_0603_1608Metric
R_SENSE1: 10m; R_0603_1608Metric
R_STAT1: 1.5k; R_0603_1608Metric
R_T1: 16k; R_0603_1608Metric
R_T2: 6.2k; R_0603_1608Metric
R_VBATT1: 33k; R_0603_1608Metric
U1: MP2672AGD-0000-Z; QFN-18_MP2672A_MNP
U5: MAX17205G+; 21-0137_T1433&plus_2C_MXM

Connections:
ALRT: U5.8 (ALRT1); also elsewhere on the board
BATT1+: C_BATT1.1, R_BATT1.1, U1.10 (BATT); also elsewhere on the board
BATT1-: R_SENSE1.1, U5.2 (CSP); also elsewhere on the board
BATT1M: R_MID1.1; also elsewhere on the board
BATT_GND: NT3.1; also elsewhere on the board
CHG_IN: C_IN1.1, L_1.1, R_H1.2, U1.1 (IN); also elsewhere on the board
CHG_OUT1: C_SYS1.1, C_SYS2.1, U1.11 (SYS); also elsewhere on the board
GND: C_BATT1.2, C_BATT2.1, C_IN1.2, C_REG2.2, C_REG3.1, C_SYS1.2, C_SYS2.2, D_SCL1.2 (A), D_SDA1.2 (A), NT2.2, U1.13 (PGND), U1.14 (SCL), U1.15 (SDA), U5.6 (CELL2), U5.7 (CELL1), U5.9 (AIN1), U5.10 (AIN2), U5.13 (CELLX); also elsewhere on the board
GNDA1: C_VCC1.1, NT2.1, R_ISET1.2, R_L1.1, R_VBATT1.2, U1.6 (AGND)
I2C1_SCL: R_SCL1.2; also elsewhere on the board
I2C1_SDA: R_SDA1.2; also elsewhere on the board
NTC1: R_T2.2; also elsewhere on the board
unnamed: C_BST1.2, L_1.2, U1.2 (SW)
unnamed: D_SCL1.1 (K), R_SCL1.1, U5.11 (OD/SCL)
unnamed: D_SDA1.1 (K), R_SDA1.1, U5.12 (DQ/SDA)
unnamed: LED_ACOK1.2 (A), R_ACOK1.1
unnamed: LED_ACOK1.1 (K), U1.18 (*ACOK)
unnamed: LED_STAT1.2 (A), R_STAT1.2
unnamed: LED_STAT1.1 (K), U1.16 (*STAT)
unnamed: C_BST1.1, U1.3 (BST)
unnamed: R_VBATT1.1, U1.17 (CV)
unnamed: R_ISET1.1, U1.5 (ISET)
unnamed: R_MID1.2, U1.9 (MID)
unnamed: R_T1.2, R_T2.1, U1.8 (NTC)
unnamed: C_VCC1.2, R_ACOK1.2, R_STAT1.1, R_T1.1, U1.4 (VCC)
unnamed: R_H1.1, R_L1.2, U1.7 (VLIM)
unnamed: NT3.2, R_SENSE1.2, U5.4 (CSN), U5.15 (EP)
unnamed: C_REG2.1, U5.3 (REG2)
unnamed: C_REG3.2, U5.1 (REG3)
unnamed: C_BATT2.2, R_BATT1.2, U5.5 (VBATT)

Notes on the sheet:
changed: SW, BST, BATT, MID to passive, SYS, VCC to power output
FUEL GAUGE
can't find value of R_MID on datasheet anywhere so I put 0 for now
CHARGER
50 ohm R_MID value from fuel gauge datasheet
Move resistors except for R_NTC onto EPS, measure from node between R2 and RNTC
not using thermistor, leave THRM AIN1 AIN2 disconnected?
Find something in datasheet that sets pulse period/initiates a reading Likely an I2C
Green LED: LTST-C171KGKT Orange LED: LTST-C170KFKT

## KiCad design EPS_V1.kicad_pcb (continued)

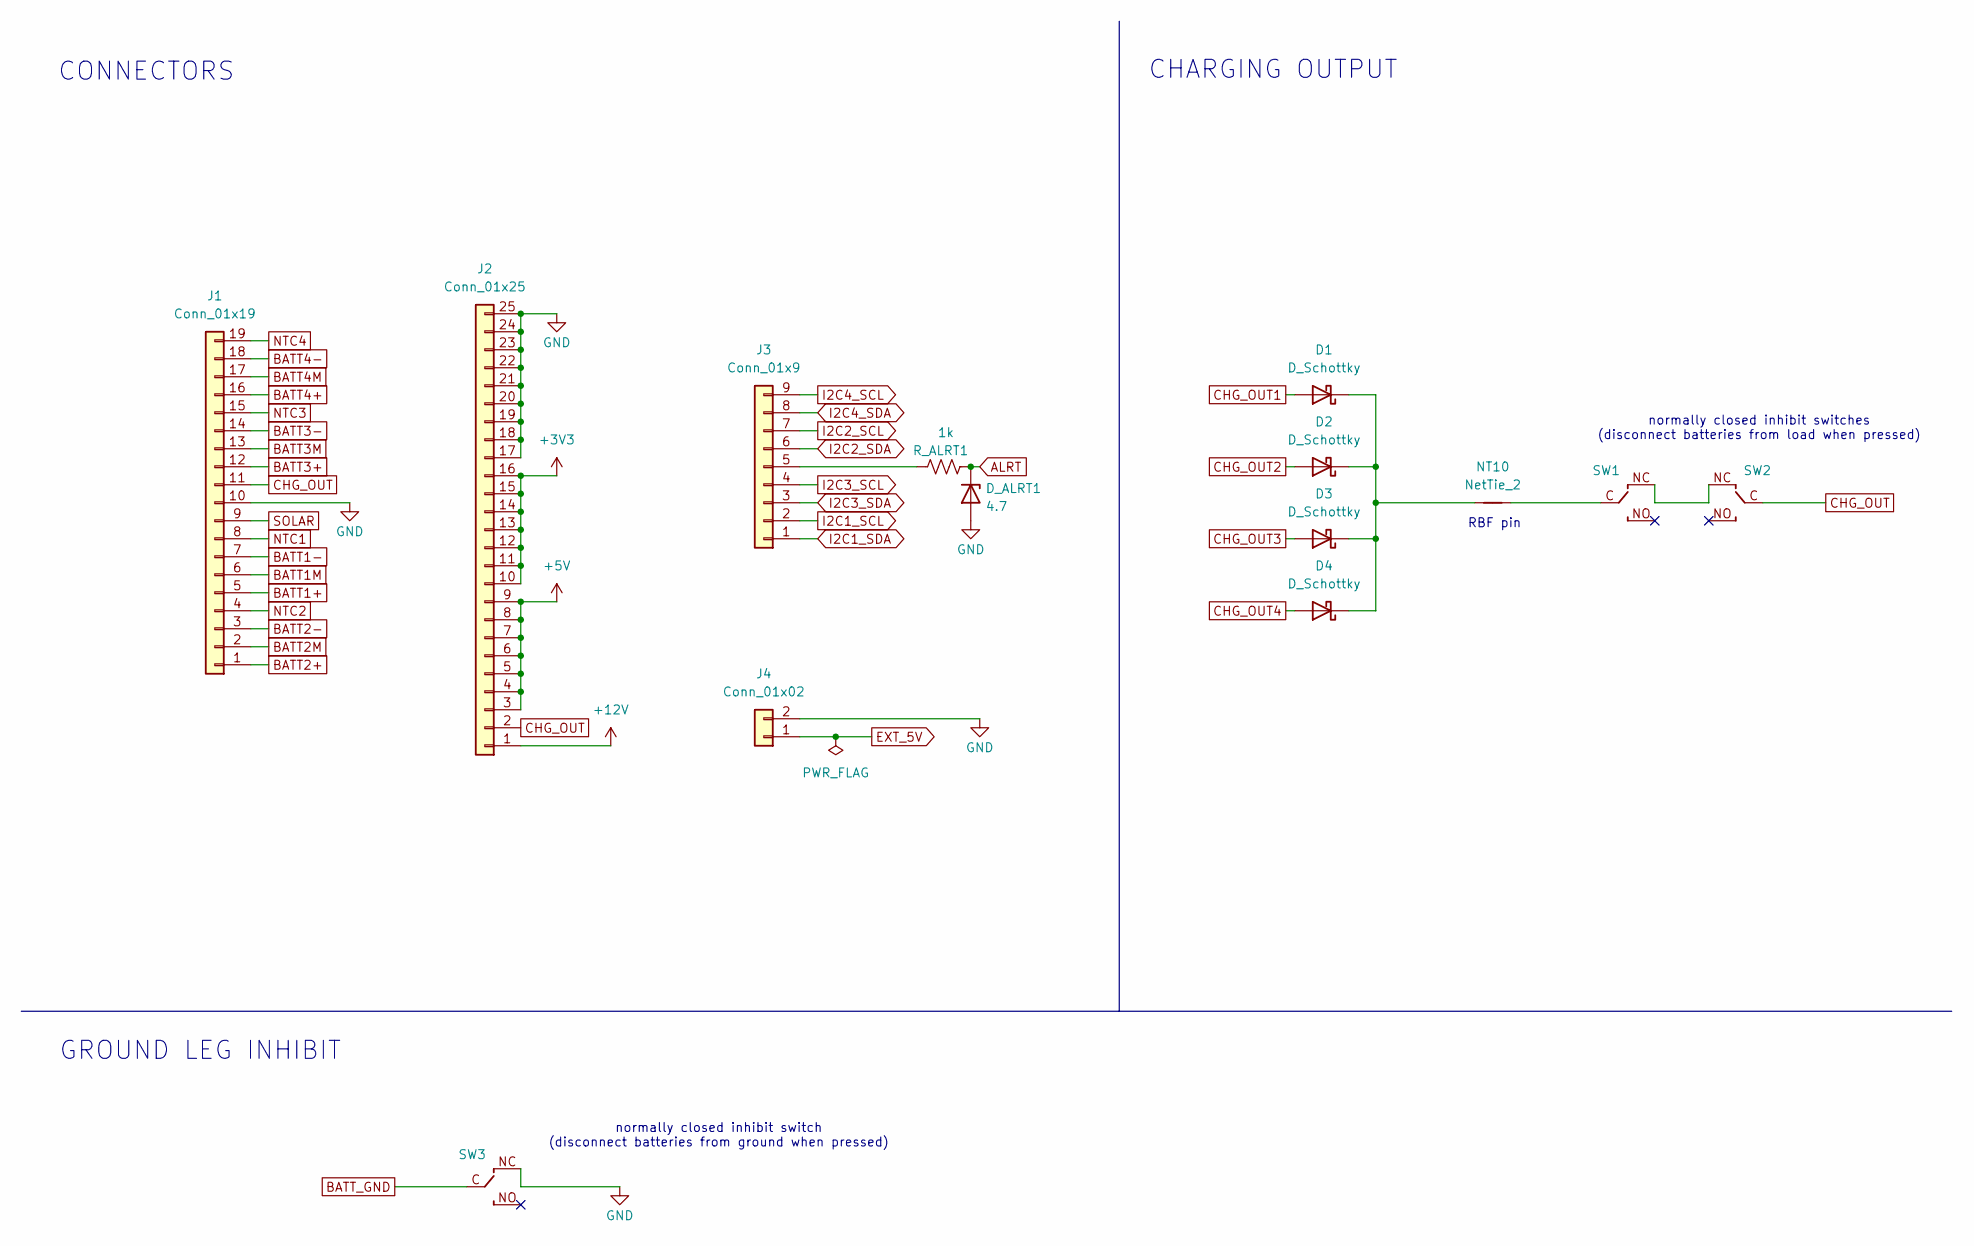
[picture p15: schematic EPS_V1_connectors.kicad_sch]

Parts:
D1, D2, D3, D4: D_Schottky; D_SOD-128; MPN RSX301LAM30TR
D_ALRT1: 4.7; D_0603_1608Metric; MPN TVSL02V05C005 (check)
J1: Conn_01x19; PinHeader_1x19_P2.54mm_Vertical
J2: Conn_01x25; PinHeader_1x25_P2.54mm_Vertical
J3: Conn_01x9; PinHeader_1x09_P2.54mm_Vertical
J4: Conn_01x02; PinHeader_1x02_P2.54mm_Vertical
NT10: NetTie_2; RBF
R_ALRT1: 1k; R_0603_1608Metric
SW1, SW3: SWITCH; SWITCH-R
SW2: SWITCH; SWITCH-L

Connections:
+3V3: J2.10, J2.11, J2.12, J2.13, J2.14, J2.15, J2.16; also elsewhere on the board
+5V: J2.3, J2.4, J2.5, J2.6, J2.7, J2.8, J2.9; also elsewhere on the board
+12V: J2.1; also elsewhere on the board
ALRT: D_ALRT1.1 (K), R_ALRT1.1; also elsewhere on the board
BATT1+: J1.5; also elsewhere on the board
BATT1-: J1.7; also elsewhere on the board
BATT1M: J1.6; also elsewhere on the board
BATT2+: J1.1; also elsewhere on the board
BATT2-: J1.3; also elsewhere on the board
BATT2M: J1.2; also elsewhere on the board
BATT3+: J1.12; also elsewhere on the board
BATT3-: J1.14; also elsewhere on the board
BATT3M: J1.13; also elsewhere on the board
BATT4+: J1.16; also elsewhere on the board
BATT4-: J1.18; also elsewhere on the board
BATT4M: J1.17; also elsewhere on the board
BATT_GND: SW3.C (COM); also elsewhere on the board
CHG_OUT: J1.11, J2.2, SW2.C (COM); also elsewhere on the board
CHG_OUT1: D1.2 (A); also elsewhere on the board
CHG_OUT2: D2.2 (A); also elsewhere on the board
CHG_OUT3: D3.2 (A); also elsewhere on the board
CHG_OUT4: D4.2 (A); also elsewhere on the board
EXT_5V: J4.1; also elsewhere on the board
GND: D_ALRT1.2 (A), J1.10, J2.17, J2.18, J2.19, J2.20, J2.21, J2.22, J2.23, J2.24, J2.25, J4.2, SW3.NC; also elsewhere on the board
I2C1_SCL: J3.2; also elsewhere on the board
I2C1_SDA: J3.1; also elsewhere on the board
I2C2_SCL: J3.7; also elsewhere on the board
I2C2_SDA: J3.6; also elsewhere on the board
I2C3_SCL: J3.4; also elsewhere on the board
I2C3_SDA: J3.3; also elsewhere on the board
I2C4_SCL: J3.9; also elsewhere on the board
I2C4_SDA: J3.8; also elsewhere on the board
NTC1: J1.8; also elsewhere on the board
NTC2: J1.4; also elsewhere on the board
NTC3: J1.15; also elsewhere on the board
NTC4: J1.19; also elsewhere on the board
unnamed: D1.1 (K), D2.1 (K), D3.1 (K), D4.1 (K), NT10.1
unnamed: J3.5, R_ALRT1.2
unnamed: NT10.2, SW1.C (COM)
unnamed: SW1.NC, SW2.NC
SOLAR: J1.9; also elsewhere on the board

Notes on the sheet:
CONNECTORS
RBF pin
normally closed inhibit switch (disconnect batteries from ground when pressed)
GROUND LEG INHIBIT
normally closed inhibit switches (disconnect batteries from load when pressed)
CHARGING OUTPUT

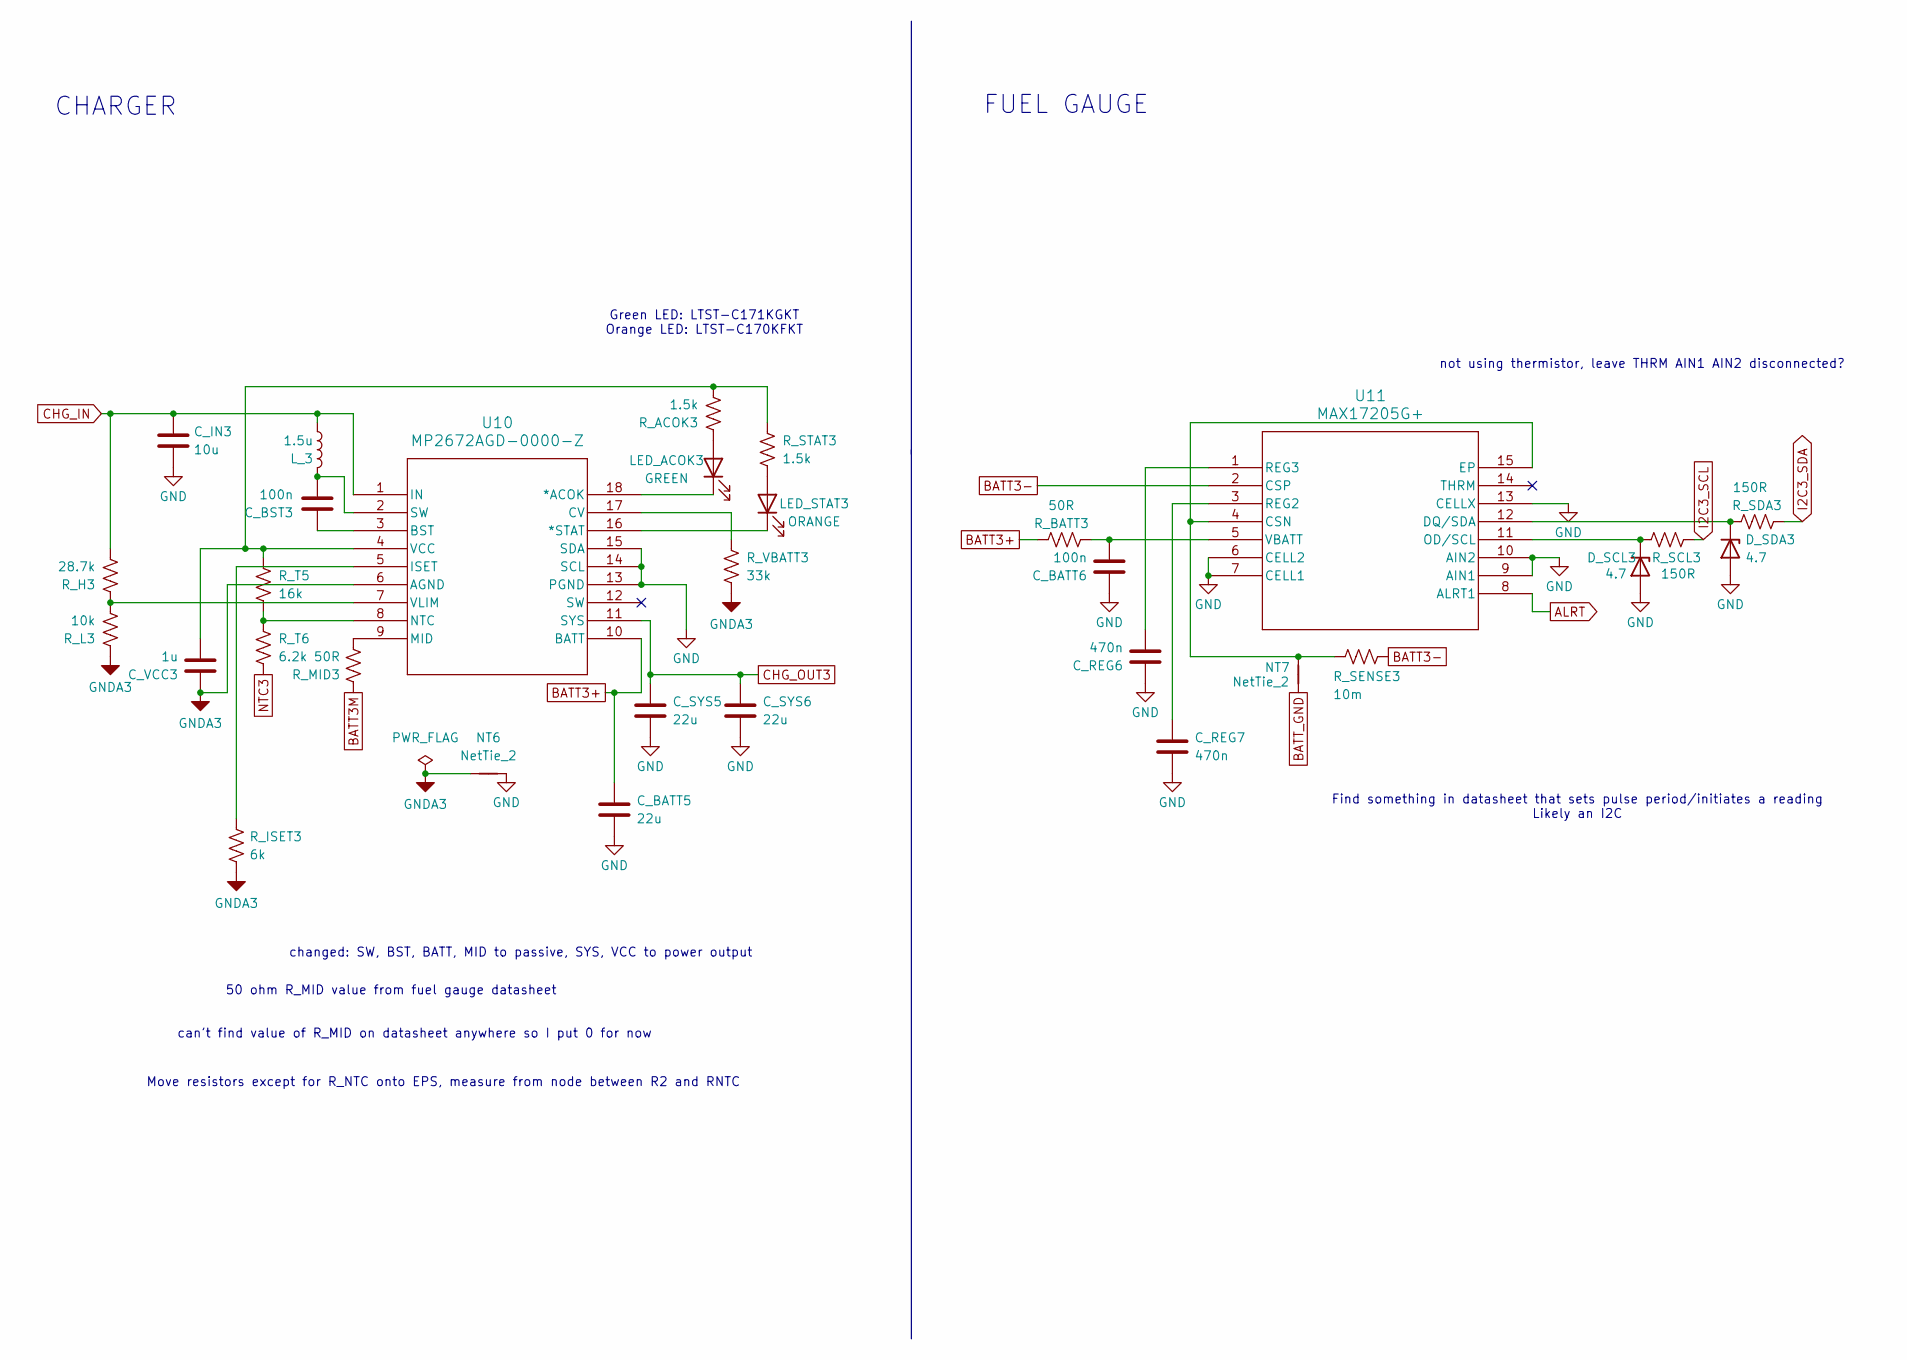
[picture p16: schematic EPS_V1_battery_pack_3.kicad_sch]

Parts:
C_BATT5: 22u; C_0805_2012Metric; Voltage Rating 25V
C_BATT6: 100n; C_0603_1608Metric; Voltage Rating 16V
C_BST3: 100n; C_0603_1608Metric; Voltage Rating 16V
C_IN3: 10u; C_0805_2012Metric; Voltage Rating 25V
C_REG6, C_REG7: 470n; C_0603_1608Metric; Voltage Rating 16V
C_SYS5, C_SYS6: 22u; C_0805_2012Metric; Voltage Rating 25V
C_VCC3: 1u; C_0603_1608Metric; Voltage Rating 16V
D_SCL3: 4.7; D_0603_1608Metric; MPN TVSL02V05C005 (check)
D_SDA3: 4.7; D_0603_1608Metric; MPN TVSL02V05C005 (check)
LED_ACOK3: GREEN; LED_0805_2012Metric; MPN LTST-C171KGKT
LED_STAT3: ORANGE; LED_0805_2012Metric; MPN LTST-C170KFKT
L_3: 1.5u; IND_AMELA2012S-1R5MT; MPN AMELA2012S-1R5MT
NT6, NT7: NetTie_2; NetTie-2_SMD_Pad0.5mm
R_ACOK3: 1.5k; R_0603_1608Metric
R_BATT3: 50R; R_0603_1608Metric
R_H3: 28.7k; R_0603_1608Metric
R_ISET3: 6k; R_0603_1608Metric
R_L3: 10k; R_0603_1608Metric
R_MID3: 50R; R_0603_1608Metric
R_SCL3: 150R; R_0603_1608Metric
R_SDA3: 150R; R_0603_1608Metric
R_SENSE3: 10m; R_0603_1608Metric
R_STAT3: 1.5k; R_0603_1608Metric
R_T5: 16k; R_0603_1608Metric
R_T6: 6.2k; R_0603_1608Metric
R_VBATT3: 33k; R_0603_1608Metric
U10: MP2672AGD-0000-Z; QFN-18_MP2672A_MNP
U11: MAX17205G+; 21-0137_T1433&plus_2C_MXM

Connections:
ALRT: U11.8 (ALRT1); also elsewhere on the board
BATT3+: C_BATT5.1, R_BATT3.1, U10.10 (BATT); also elsewhere on the board
BATT3-: R_SENSE3.1, U11.2 (CSP); also elsewhere on the board
BATT3M: R_MID3.1; also elsewhere on the board
BATT_GND: NT7.1; also elsewhere on the board
CHG_IN: C_IN3.1, L_3.1, R_H3.2, U10.1 (IN); also elsewhere on the board
CHG_OUT3: C_SYS5.1, C_SYS6.1, U10.11 (SYS); also elsewhere on the board
GND: C_BATT5.2, C_BATT6.1, C_IN3.2, C_REG6.1, C_REG7.2, C_SYS5.2, C_SYS6.2, D_SCL3.2 (A), D_SDA3.2 (A), NT6.2, U10.13 (PGND), U10.14 (SCL), U10.15 (SDA), U11.6 (CELL2), U11.7 (CELL1), U11.9 (AIN1), U11.10 (AIN2), U11.13 (CELLX); also elsewhere on the board
GNDA3: C_VCC3.1, NT6.1, R_ISET3.2, R_L3.1, R_VBATT3.2, U10.6 (AGND)
I2C3_SCL: R_SCL3.2; also elsewhere on the board
I2C3_SDA: R_SDA3.2; also elsewhere on the board
NTC3: R_T6.2; also elsewhere on the board
unnamed: C_BST3.2, L_3.2, U10.2 (SW)
unnamed: D_SCL3.1 (K), R_SCL3.1, U11.11 (OD/SCL)
unnamed: D_SDA3.1 (K), R_SDA3.1, U11.12 (DQ/SDA)
unnamed: LED_ACOK3.2 (A), R_ACOK3.1
unnamed: LED_ACOK3.1 (K), U10.18 (*ACOK)
unnamed: LED_STAT3.2 (A), R_STAT3.2
unnamed: LED_STAT3.1 (K), U10.16 (*STAT)
unnamed: C_BST3.1, U10.3 (BST)
unnamed: R_VBATT3.1, U10.17 (CV)
unnamed: R_ISET3.1, U10.5 (ISET)
unnamed: R_MID3.2, U10.9 (MID)
unnamed: R_T5.2, R_T6.1, U10.8 (NTC)
unnamed: C_VCC3.2, R_ACOK3.2, R_STAT3.1, R_T5.1, U10.4 (VCC)
unnamed: R_H3.1, R_L3.2, U10.7 (VLIM)
unnamed: NT7.2, R_SENSE3.2, U11.4 (CSN), U11.15 (EP)
unnamed: C_REG7.1, U11.3 (REG2)
unnamed: C_REG6.2, U11.1 (REG3)
unnamed: C_BATT6.2, R_BATT3.2, U11.5 (VBATT)

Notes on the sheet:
Move resistors except for R_NTC onto EPS, measure from node between R2 and RNTC
Green LED: LTST-C171KGKT Orange LED: LTST-C170KFKT
can't find value of R_MID on datasheet anywhere so I put 0 for now
FUEL GAUGE
CHARGER
changed: SW, BST, BATT, MID to passive, SYS, VCC to power output
50 ohm R_MID value from fuel gauge datasheet
not using thermistor, leave THRM AIN1 AIN2 disconnected?
Find something in datasheet that sets pulse period/initiates a reading Likely an I2C

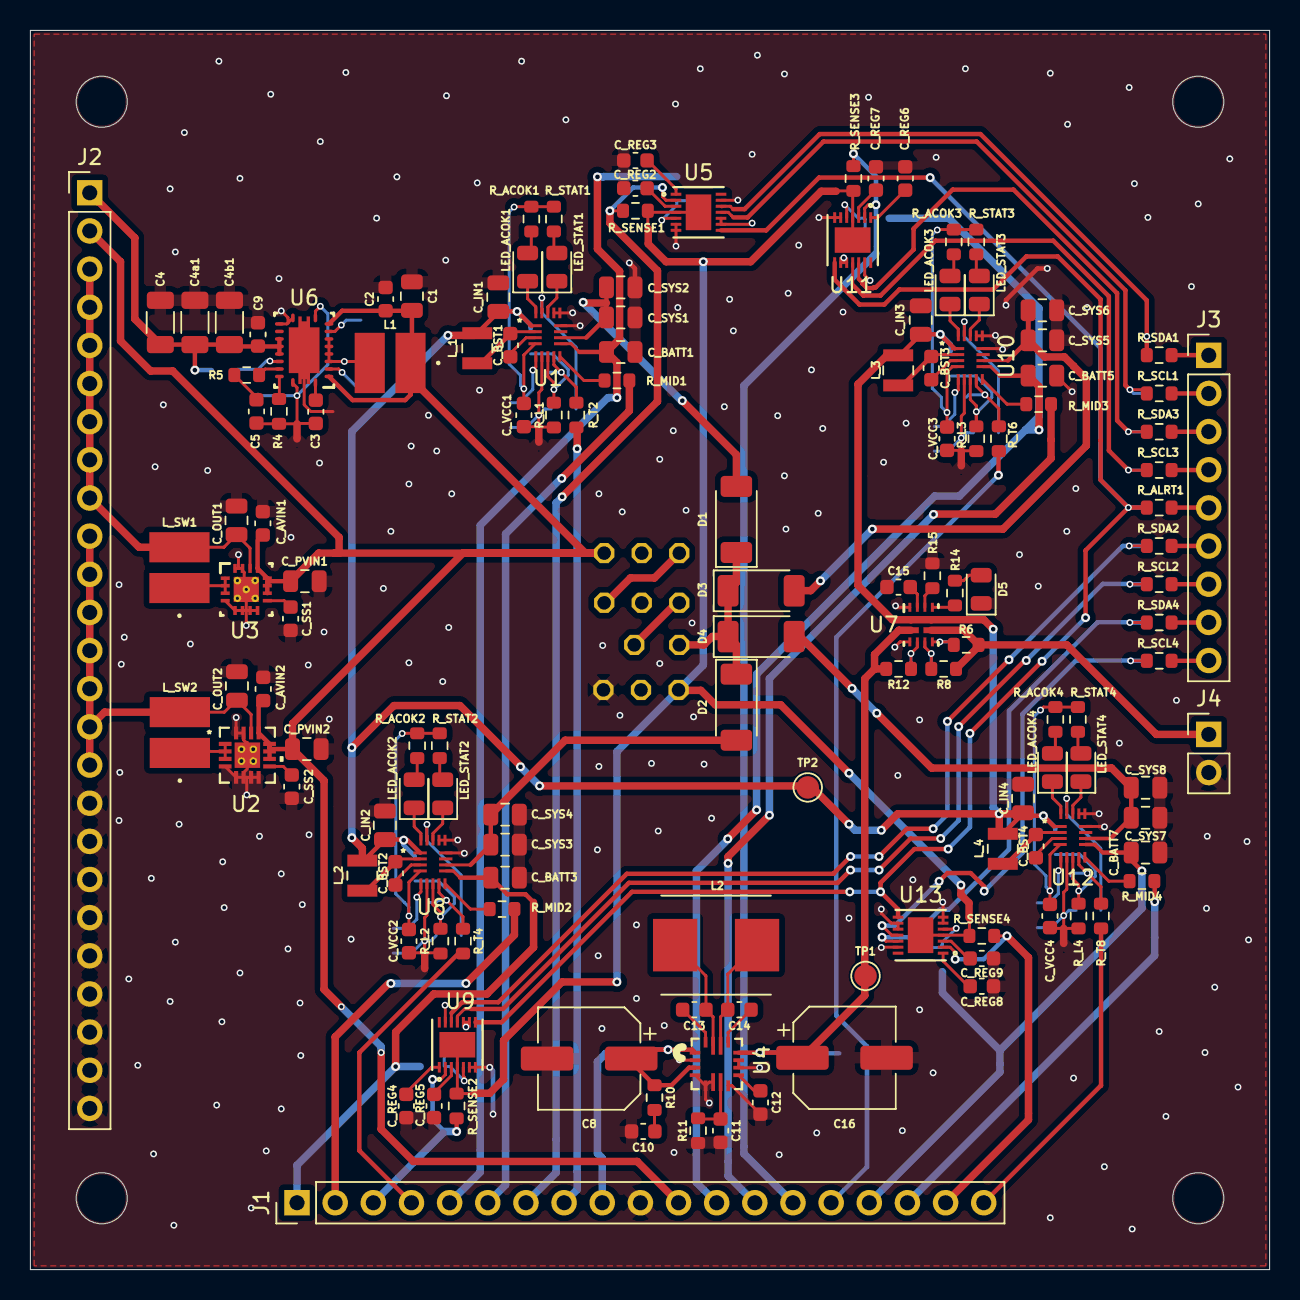
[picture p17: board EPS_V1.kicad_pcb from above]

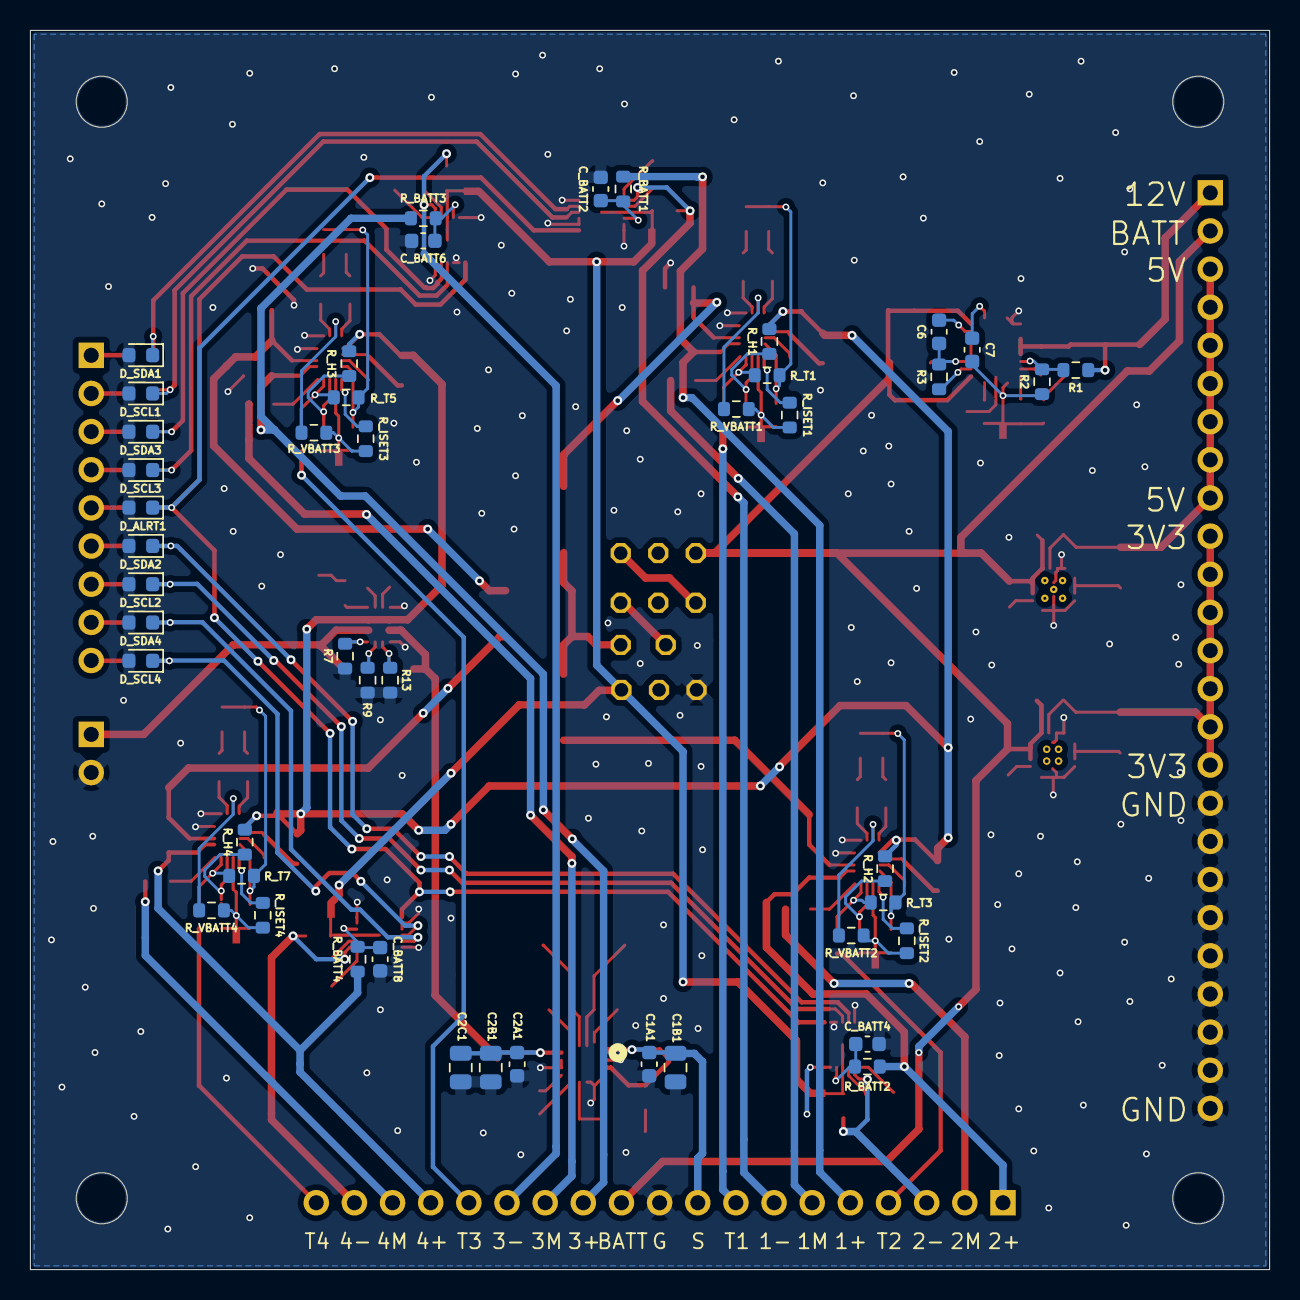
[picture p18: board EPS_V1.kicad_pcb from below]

Board: 2 copper layers, 82.5 x 82.5 mm, 197 parts (46 on the bottom side), 147 nets.

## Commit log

2026-04-18 Add connectors, 5V & 3V3 buck converters, 1 battery pack & charger
    [EPS_V1.kicad_sch, EPS_V1_battery_pack_1.kicad_sch, EPS_V1_connectors.kicad_sch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]
2026-04-18 Minor fixes
    [EPS_V1_battery_pack_1.kicad_sch, EPS_V1_converters.kicad_sch]
2026-04-21 Add solar to charger buck-boost converter, make charger standalone instead of host control
    [EPS_V1_battery_pack_1.kicad_sch, EPS_V1_converters.kicad_sch]
2026-04-23 Add fuel gauge, fix voltage labels
    [EPS_V1_battery_pack_1.kicad_sch, EPS_V1_connectors.kicad_sch, EPS_V1_converters.kicad_sch]
2026-04-23 Add fuel gauge ALRT lines
    [EPS_V1_battery_pack_1.kicad_sch, EPS_V1_connectors.kicad_sch]
2026-04-26 Add boost converter to 12V, fix grounding
    [EPS_V1_battery_pack_1.kicad_sch, EPS_V1_connectors.kicad_sch, EPS_V1_converters.kicad_sch]
2026-04-29 Add 12V boost values
    [EPS_V1_battery_pack_1.kicad_sch, EPS_V1_connectors.kicad_sch, EPS_V1_converters.kicad_sch]
2026-04-29 Add 5V charging input
    [EPS_V1_connectors.kicad_sch, EPS_V1_converters.kicad_sch]
2026-04-30 Clarify global net naming, other minor fixes
    [EPS_V1_battery_pack_1.kicad_sch, EPS_V1_connectors.kicad_sch, EPS_V1_converters.kicad_sch]
2026-04-30 Add inhibit switches
    [EPS_V1_connectors.kicad_sch]
2026-05-01 Add all footprints except connectors & switches, change to net ties over 0 ohm resistors
    [AMELA2012S-1R5MT.step, ASPI-7318-4R7M-T.step, EPS_V1_battery_pack_1.kicad_sch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]
2026-05-01 Clean up & add labels
    [EPS_V1_battery_pack_1.kicad_sch, EPS_V1_connectors.kicad_sch, EPS_V1_converters.kicad_sch]
2026-05-01 Add notes from Harvey meeting
    [EPS_V1.kicad_sch, EPS_V1_battery_pack_1.kicad_sch, EPS_V1_connectors.kicad_sch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]
2026-05-02 assigned footprints to headers
    [EPS_V1_connectors.kicad_sch]
2026-05-03 Add power switching IC
    [EPS_V1.kicad_sch, EPS_V1_battery_pack_1.kicad_sch, EPS_V1_connectors.kicad_sch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]
2026-05-04 Add other battery packs, connect all ALRT signals, assign footprints for new components, make inhibit switch footprints
    [EPS_V1.kicad_sch, EPS_V1_battery_pack_2.kicad_sch, EPS_V1_battery_pack_3.kicad_sch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]
2026-05-04 Change new resistors to standard values
    [EPS_V1_battery_pack_2.kicad_sch, EPS_V1_battery_pack_3.kicad_sch, EPS_V1_battery_pack_4.kicad_sch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]
2026-05-15 Do layout draft
    [EPS_V1.kicad_pcb, EPS_V1_battery_pack_1.kicad_sch, EPS_V1_battery_pack_2.kicad_sch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]
2026-08-03 Add CHG_OUT for heaters
    [.step, EPS_V1.kicad_pcb, EPS_V1_connectors.kicad_sch]
2026-08-06 generate 3d step file
    [EPS_V1.step]
2026-08-06 Reorganize imported components into libs/, removed fluff
    [.step]
2026-08-07 Relink footprint references to consolidated libs/footprints.pretty
    [EPS_V1.kicad_pcb, EPS_V1_battery_pack_1.kicad_sch, EPS_V1_battery_pack_2.kicad_sch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]
2026-08-07 Move auxiliary schematic sheets into schematics/, update sheet references
    [EPS_V1.kicad_sch, EPS_V1_battery_pack_1.kicad_sch, EPS_V1_battery_pack_2.kicad_sch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]
2026-08-07 Update project file zone defaults (KiCad auto-normalization on open)
2026-08-07 Add .gitattributes to normalize KiCad file line endings
2026-08-07 Bulk-update footprints from library, add remaining 3D models, regenerate STEP export
    [EPS_V1.kicad_pcb, EPS_V1.step]
2026-08-07 added README, restored .step
    [EPS_V1.step]
2026-08-09 Expose unregulated battery voltage for burn wire
    [EPS_V1.kicad_pcb, EPS_V1_connectors.kicad_sch]
2026-08-21 Fix NC pins, add 2 test points & silkscreen labels
    [EPS_V1.kicad_pcb, EPS_V1_battery_pack_1.kicad_sch, EPS_V1_battery_pack_2.kicad_sch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]
2026-08-25 Fix silkscreen; Fix component value style
    [EPS_V1.kicad_pcb, EPS_V1_battery_pack_1.kicad_sch, EPS_V1_battery_pack_2.kicad_sch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]
2026-08-25 regenerate STEP file
    [EPS_V1.step]
2026-08-26 fix silkscreen again...
    [EPS_V1.kicad_pcb]
2026-08-30 Remove extra solder paste areas from MP2672A footprints
    [EPS_V1-B_Cu.gbr, EPS_V1-B_Mask.gbr, EPS_V1-B_Paste.gbr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]
2026-09-04 file reorg
    [EPS_V1-B_Cu.gbr, EPS_V1-B_Mask.gbr, EPS_V1-B_Paste.gbr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]
2026-09-29 regen STEP
    [EPS_V1.step]
